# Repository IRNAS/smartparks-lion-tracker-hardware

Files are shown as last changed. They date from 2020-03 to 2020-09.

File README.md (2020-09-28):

# Smart Parks Lion Tracker Hardware

# Lion Tracker Hardware
 

<br>

PCB view:
<p align="center">
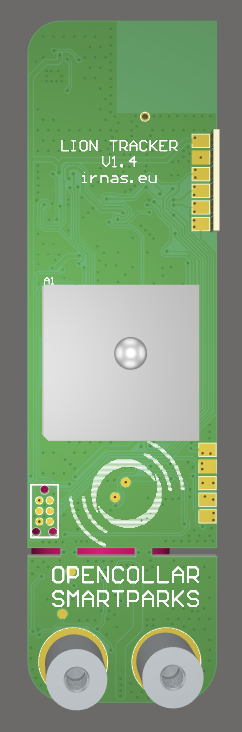
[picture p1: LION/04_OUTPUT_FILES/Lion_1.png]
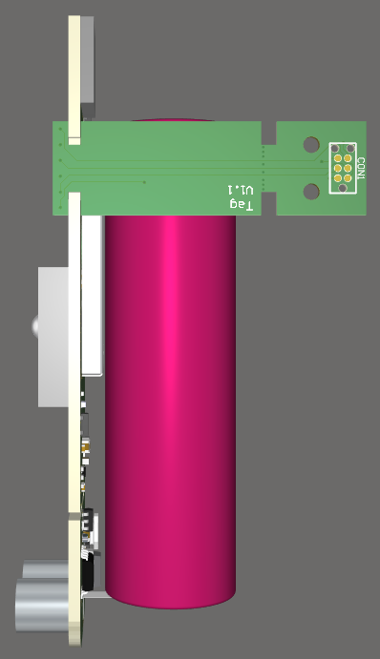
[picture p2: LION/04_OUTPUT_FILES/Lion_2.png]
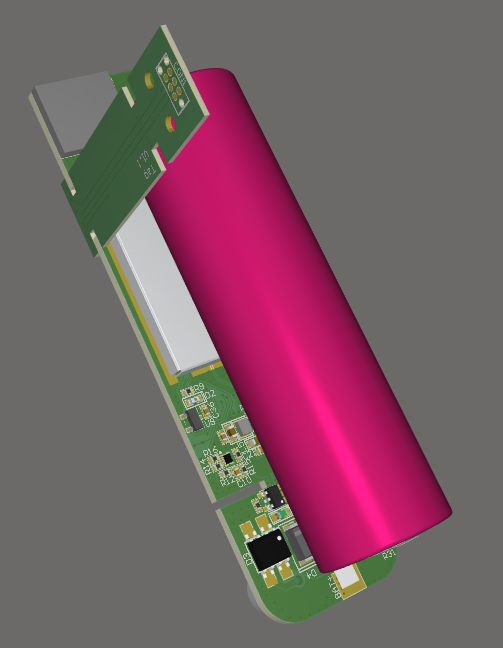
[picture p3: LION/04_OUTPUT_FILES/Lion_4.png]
							
</p>

Potted view:
<p align="center">
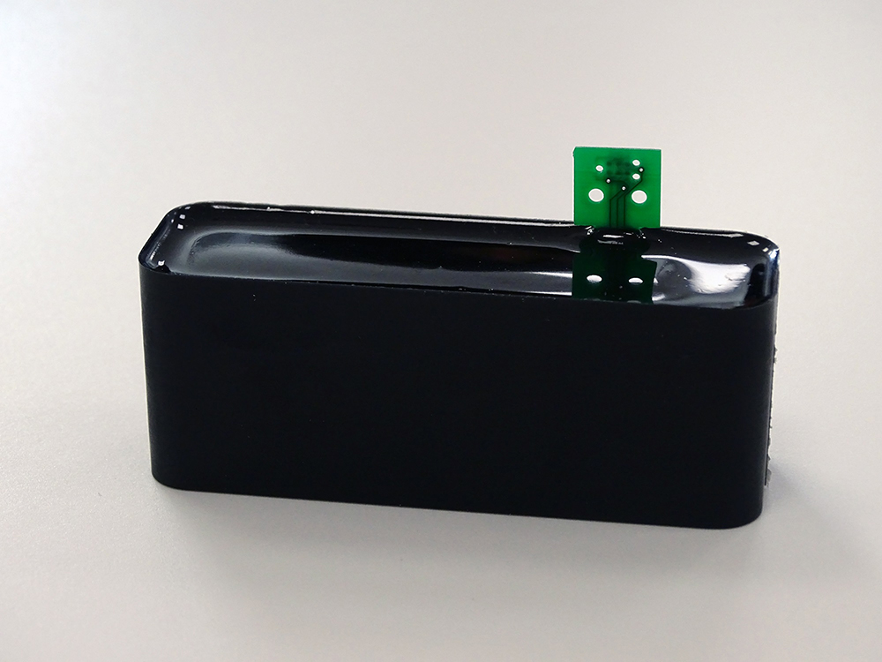
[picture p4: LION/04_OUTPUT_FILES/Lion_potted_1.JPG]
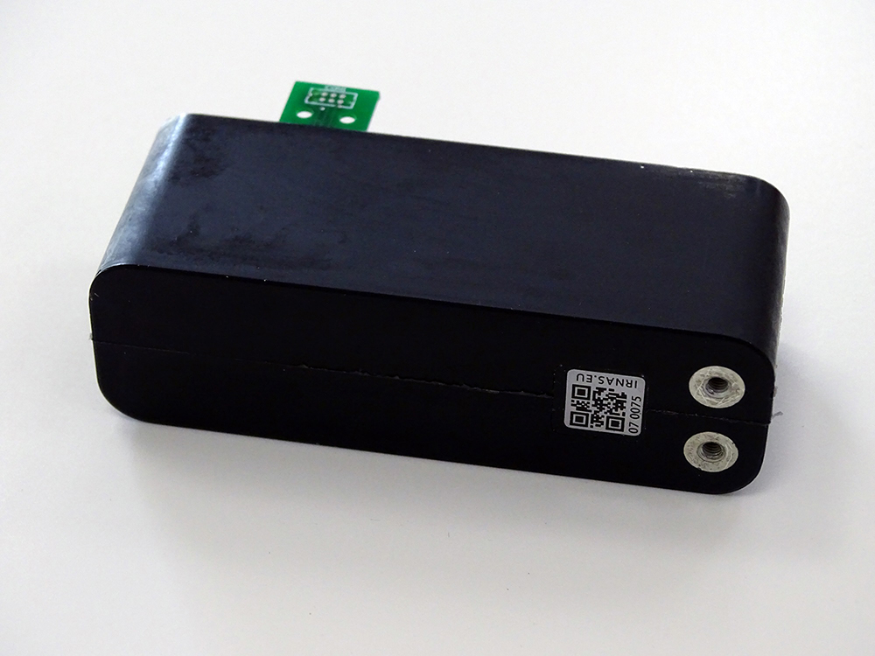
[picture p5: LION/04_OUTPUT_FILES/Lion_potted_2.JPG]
			
</p>

- PCB specifications:
	- 1.6mm PCB thinknes
	- 0.152mm (6mil) trace to trace and trace to polygon clearance
	- 1mm RF line thinknes

- Mehanical specifications:
	- Device dimensions 87x28x33mm
	- Device weight: ~125g
	- Device is put in polyurethane resin to protect it (https://electrolube.com/product/ur5528-chemically-resistant-polyurethane-resin/)
	- Inside of the device is EMC shield around MCU and RF components to protect them from resin
	- Resin thinknes arount the device is 2mm

- Future changes:
	- TBD
	
# Lence monitor add-on

- PCB specifications:
	- 1.6mm PCB thinknes
	- 0.152mm (6mil) trace to trace and trace to polygon clearance
	- Extra 3mm cut-out for protecting measuring circuit from high voltage discharge
	- Used as add-on for lion tracker
	
<p align="center">
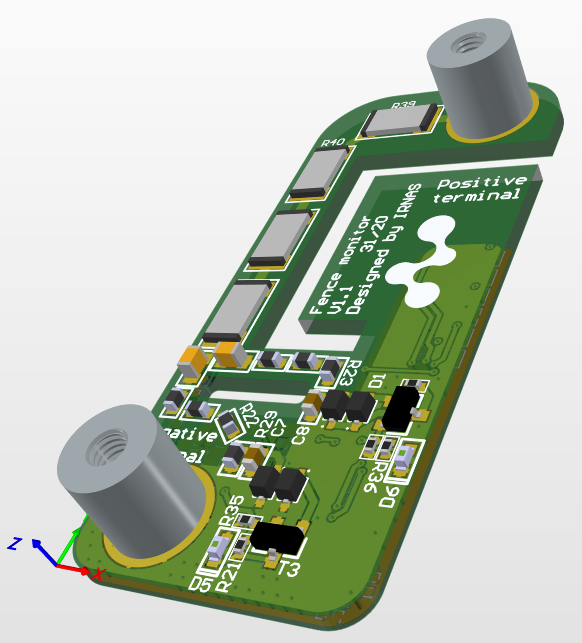
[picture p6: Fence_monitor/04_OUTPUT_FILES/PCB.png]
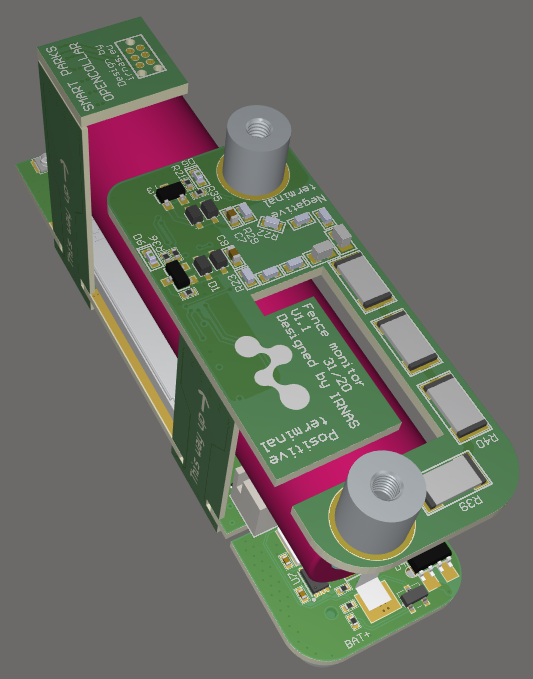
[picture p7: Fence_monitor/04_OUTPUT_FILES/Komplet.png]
			
</p>
	
Currently under development, for all information see the [schematic PDF file](https://github.com/IRNAS/smartparks-lion-tracker-hardware/blob/master/LION/06_RELEASE/V1.3/Lion_Tracker_V1.3_SCHEMATICS/Lion_Tracker_V1.3_SCHEMATICS.PDF).Produced board versions can be found in the [release section](https://github.com/IRNAS/smartparks-lion-tracker-hardware/releases) of the repository.

**Latest release: [v1.5](https://github.com/IRNAS/smartparks-lion-tracker-hardware)**

All comments and suggestions can be added to the [Issues](https://github.com/IRNAS/smartparks-lion-tracker-hardware/issues) section of the repo.

---

## Licensing

Lion tracker hardware with documentation is licensed under [CERN OHL v.1.2. license](https://www.ohwr.org/licenses/cern-ohl/license_versions/v1.2).

What this means is that you can use this hardware and documentation without paying a royalty and knowing that you'll be able to use your version forever. You are also free to make changes but if you share these changes then you have to do so on the same conditions that you enjoy.

IRNAS is name and mark of Institute IRNAS Rače. You may use these name and terms only to attribute the appropriate entity as required by the Open Licence referred to above. You may not use them in any other way and in particular you may not use them to imply endorsement or authorization of any hardware that you design, make or sell.

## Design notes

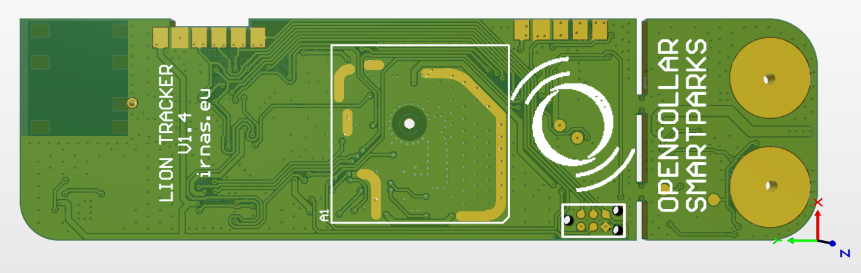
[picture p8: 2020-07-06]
LION/04_OUTPUT_FILES/Lion_5.png

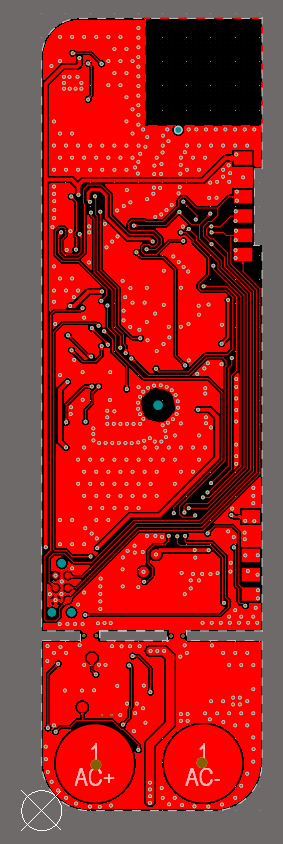
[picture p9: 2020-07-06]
LION/04_OUTPUT_FILES/Lion_8.png

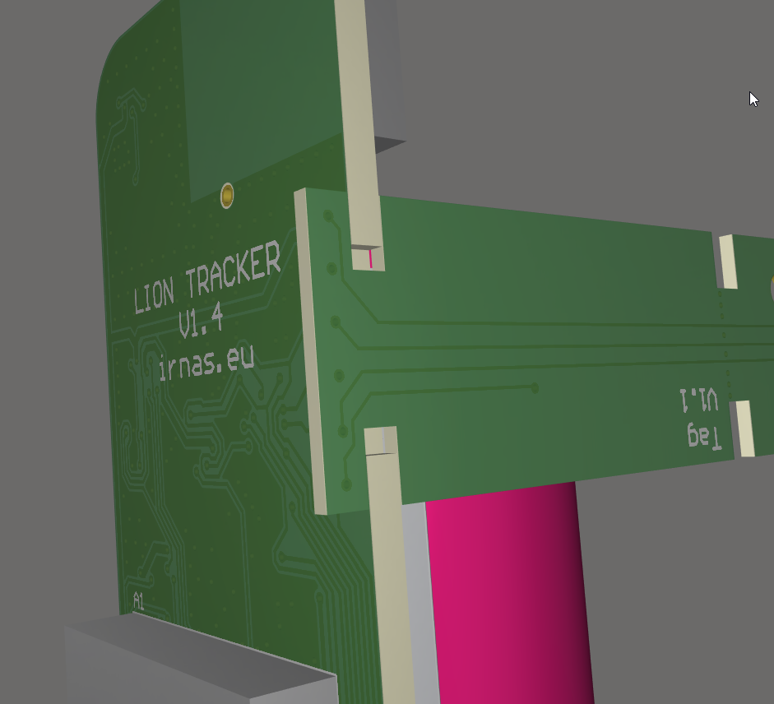
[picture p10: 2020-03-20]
LION/04_OUTPUT_FILES/Lion_3.png

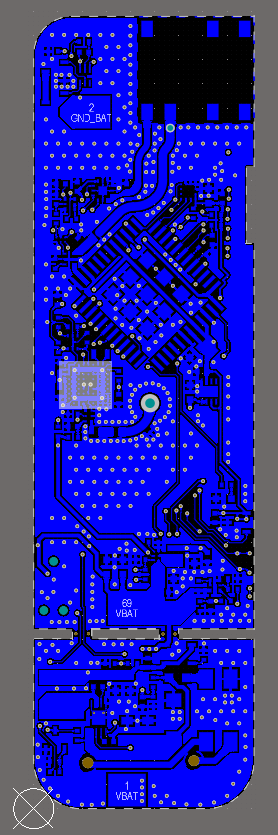
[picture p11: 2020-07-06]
LION/04_OUTPUT_FILES/Lion_7.png

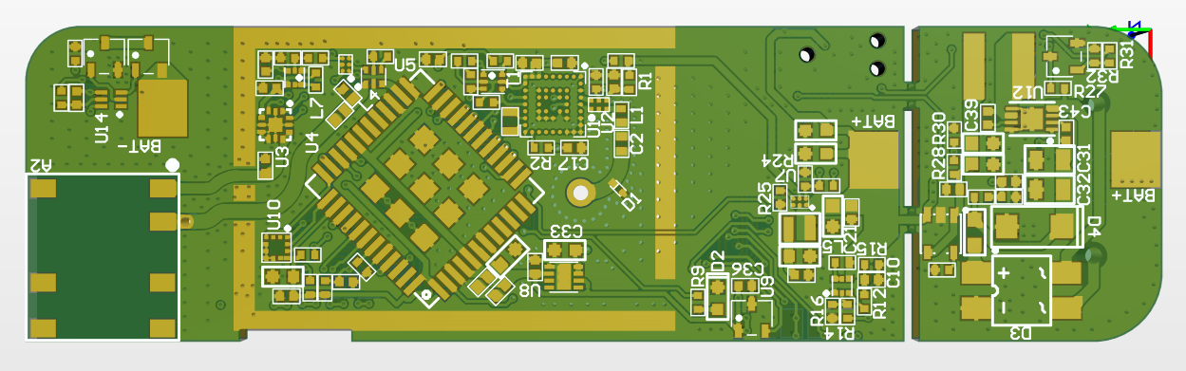
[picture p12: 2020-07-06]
LION/04_OUTPUT_FILES/Lion_6.png

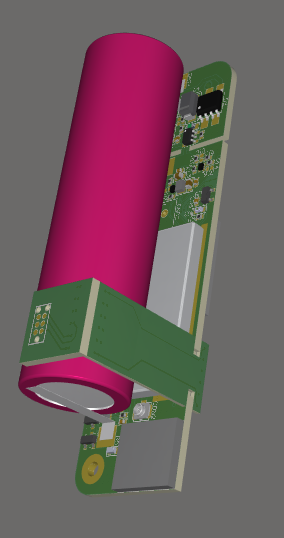
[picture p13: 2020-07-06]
LION/04_OUTPUT_FILES/Lion_10.png

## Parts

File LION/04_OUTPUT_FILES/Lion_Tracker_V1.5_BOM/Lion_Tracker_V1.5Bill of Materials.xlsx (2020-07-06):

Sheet: Part List Report
 | Component list |  |  | Lion_Tracker
 | Source Data From: | Lion tracker.PrjPCB
 | Project: | Lion tracker.PrjPCB
 | Variant: | BASIC |  |  | IRNAS
 | Report Date: | 12. 05. 2020 | 13:15 |  | www.irnas.eu
 | Print Date: | 2020-05-12 | 14:35:35
# | Manufacturer Part Number | Manufacturer | Description | Footprint | Designator | Quantity | Supplier 1 | Supplier Part Number 1
1 | 9HT11-32.768KEZC-T | TXC | Crystal, 32.768 kHz, SMD, 2mm x 1.2mm, 9 pF, 10 ppm, 9HT11 Series | 9HT11 | X1 | 1 | Farnell | 2819312
2
3 | MC0402X104J160CT | Multicomp | 0.1 F, 16 V, 5%, X5R, MC Series | CAP0402 | C4, C6, C8, C11, C14, C16, C21, C22, C39, C45 | 10 | Farnell | 2627419
4 | MC0402N3R9C500CT | KEMET | 3.9 pF, 50 V, 0402 [1005 Metric], ± 0.25pF, NP0 | CAP0402 | C7 | 1 | Farnell | 2627407
5 | MC0402X333K160CT | Multicomp | 33 pF, 16 V, 5%, C0G / NP0, MC Series | CAP0402 | C1 | 1 | Farnell | 1759384
6 | GRT155R71H471KE01D | Murata | 470 pF, 50 V, 0402 [1005 Metric], ± 10%, X7R, GRT Series | CAP0402 | C2 | 1 | Farnell | 2672128
7 | 0402ZD105MAT2A | Murata | CAP CER 1UF 10V 20% X5R 0402 | CAP0402 | C3, C13, C15, C36, C40, C43 | 6 | Farnell | 2332548
8 | GRM155R60J225ME15D | Murata | CAP CER 2.2UF 6.3V 20% X5R 0402 | CAP0402 | C34 | 1 | Farnell | 2362088
9 | 0402YC103KAT2A | Murata | CAP CER 10000PF 16V X7R 0402 | CAP0402 | C17 | 1 | Farnell | 1327662
10 | GRM188R61C475KAAJD | MURATA | 4.7UF, 16V, 0603 | CAP0603 | C33 | 1 | Farnell | 2611924
11 | GRM188R60G226MEA0D | Samsung | 22 µF, 4 V, 0603 [1608 Metric], ± 20%, X5R, GRM Series | CAP0603 | C23 | 1 | Farnell | 1907502
12 | CL10A106KP8NNNC | Samsung | Cap Ceramic 10uF 10V X5R 10% SMD 0603 85C Paper T/R | CAP0603 | C5, C12, C18, C19, C20, C41, C42 | 7 | Digi-Key | 3013386
13 | GRM21BR6YA106KE43L | TDK | 10UF, 35V, 0805 | CAP0805 | C31, C32 | 2 | Farnell | 2611943
14 | SMAJ33A-13-F | DIODES INC. | TVS Diode, SMAJ Series, Unidirectional, 33 V, 53.3 V, DO-214AC | DO-214AC (SMA) | D4 | 1 | Farnell | 3127459
15 | LMH2110TMX/NOPB | Texas Instruments | RF Detector IC GSM, EDGE, CDMA 50MHz ~ 8GHz -40dBm ~ 5dBm ±0,5dB | DSBGA-6 | U6 | 1 | Mouser | 926-LMH2110TMX/NOPB
16 | 0603L035YR | LITTELFUSE | LITTELFUSE - 0603L035YR - RESETTABLE FUSE, PTC, 40A, 6V, 0605 | FUSE0603 | F1 | 1 | Farnell | 2786561
17 | HHM22106C1 | TDK | Signal Conditioning DIRECTIONAL COUPLER 700-2700MHz | HHM22106C1 | U5 | 1 | Mouser | 810-HHM22106C1
18 | SRN2009T-2R2M | Bourns | Power Inductor (SMD), 2.2 µH, 900 mA, Semishielded, 900 mA, SRN2009T Series, 2mm x 1.6mm x 0.95mm | IND2.3X1.7 | L5 | 1 | Farnell | 2808272
19 | LQG15HS1N5S02D | Murata | 1.5 nH, LQG15HS_02 Series, 1 A, 0402 | IND0402 | L7 | 1 | Farnell | 2840113
20 | LQG15HS33NJ02D | Murata | High Frequency Inductor, 8.2 nH, LQG15HN Series, 300 mA, 0402 [1005 Metric], Multilayer, 0.33 ohm | IND0402 | L1 | 1 | Farnell | 1343079
21 | LIS2DW12TR | STMICROELECTRONICS | MEMS Accelerometer, Digital, X, Y, Z, ± 2g, ± 4g, ± 8g, ± 16g, 1.62 V, 3.6 V | LGA-12 | U10 | 1 | Farnell | 2849615
22 | CMWX1ZZABZ-091 | Murata | RF Module, FSK, OOK, LoRa, 4.8Kbps, 915MHz, -135.5dBm, 2.2V to 3.6V, I2C, SPI, UART, USB | Lora Module ES0 | U4 | 1 | Mouser | 81-CMWX1ZZABZ-091
23 | MB1S | ON SEMICONDUCTOR | Bridge Rectifier Diode, Single Phase, 100 V, 500 mA, SOIC, 1 V, 4 Pins | MB1S | D3 | 1 | Farnell | 1467483
24
25 | BQ29700DSET | TEXAS INSTRUMENTS | Li-Ion Battery, Li-Pol Voltage & Current Protector, Single Cell, 1.5 V to 8 V supply, | PWSON-6 | U14 | 1 | Farnell | 3123826
26 | PE64102B-Z | pSemi | RF IC Digitally Tunable Capacitor General Purpose 100MHz ~ 3GHz SPI Interface 12-QFN (2x2) | QFN-12 | U3 | 1 | Digi-Key | 1046-1066-1-ND
27 | MCWR04X2001FTL | Multicomp | 2 kohm, 62.5 mW, 1%, 50 V | RES0402 | R29 | 1 | Farnell | 2447147
28 | MCWR04X2201FTL | Multicomp | 2.2 kohm, 62.5 mW, 1%, 50 V | RES0402 | R36 | 1 | Farnell | 2447148
29 | MCWR04X1002FTL | Multicomp | 10 kohm, 50 V, 0402 [1005 Metric], 62.5 mW, 1%, MCWR Series, 10 kohm, 50 V, 0402, 62.5 mW, 1%, | RES0402 | R10, R11, R17, R18, R30, R34 | 6 | Farnell | 2447096
30 | CRCW040249R9FKED | Vishay | 49.9 ohm, CRCW e3 Series, 50 V, Thick Film, 63 mW | RES0402 | R19 | 1 | Farnell | 1469722
31 | MCMR04X5232FTL | Multicomp | 52.3 kohm, 50 V, 0402 [1005 Metric], 62.5 mW, 1%, MCWR Series | RES0402 | R28 | 1 | Farnell | 2073114
32 | MCMR04X1000FTL | Multicomp | 100 ohm, 50 V, 0402 [1005 Metric], 62.5 mW, 1% | RES0402 | R2, R14, R21, R23, R31 | 5 | Farnell | 2072515
33 | MCWR04X1003FTL | Multicomp | 100KOHM, 1%, 0.0625W | RES0402 | R4, R5, R6, R7, R8, R13, R20 | 7 | Farnell | 2447094
34 | MCWR04X3900FTL | Multicomp | 390 ohm, MCWR Series, 50 V, Thick Film, 62.5 mW | RES0402 | R15 | 1 | Farnell | 2447165
35 | MC0063W060311M | MULTICOMP | MCMR04X1004FTL RES, 1M, 1%, 0.0625W, 0402, THICK FILM | RES0402 | R3, R22, R27 | 3 | Farnell | 9330410
36 | MCMR04X3300FTL | Multicomp | MULTICOMP MCMR04X3300FTL Surface Mount Chip Resistor, Ceramic, MCMR Series, 330 ohm, 62.5 mW, 1%, 50 V, 0402 [1005 Metric], 330 ohm, 62.5 mW, 1%, 50 V, 0402 [1005 Metric] | RES0402 | R12, R35 | 2 | Farnell | 2692084
37 | MCMR04X1653FTL | Vishay | RES SMD 165K OHM 1% 1/16W 0402 | RES0402 | R33 | 1 | Farnell | 2072686
38 | MCMR04X000PTL | Multicomp | RESISTOR, 0402, 0R, ANTI SULFURATION | RES0402 | R1 | 1 | Farnell | 2072513
39 | WR04X7683FTL | Multicomp | RESISTOR, 0402, 768k, ANTI SULFURATION | RES0402 | R25 | 1 | Farnell | 2670555
40 | ZOE-M8G | U-Blox | ZOE-M8 RF Receiver BeiDou, Galileo, GLONASS, GNSS, GPS -160dBm | S-LGA51 | U1 | 1 | Digi-Key | 672-ZOE-M8G-0-10CT-ND
41 | ESD9R3.3ST5G | ON SEMICONDUCTOR | TVS Diode, ESD9R Series, Unidirectional, 3.3 V, 7.8 V | SOD-923 | D1 | 1 | Farnell | 2101835
42 | DRV5032FBDBZR | Texas Instruments | Board Mount Hall Effect/Magnetic Sensors LP HALL 32FBDBZR | SOT23-3AL | U9 | 1 | Mouser | 595-DRV5032FBDBZR
43 | DMG2302UK-7 | DIODES INC. | MOSFET Transistor, N Channel, 2.8 A, 20 V, 0.061 ohm, 4.5 V, 600 mV | SOT23-3AL | T4 | 1 | Farnell | 3127526
44 | SI2374DS-T1-GE3 | VISHAY | MOSFET Transistor, N Channel, 5.9 A, 20 V, 0.025 ohm, 4.5 V, 1 V | SOT23-3AL | T5, T6 | 2 | Farnell | 2646371
45 | MCP73812T-420I/OT | MICROCHIP | Battery Charger for 1 Cell of Li-Ion, Li-Pol battery, 6V input, 4.2V / 500mA charge | SOT23-5 | U13 | 1 | Farnell | 1627187
46 | NTZD3154NT1G | ON SEMICONDUCTOR | Dual MOSFET, Dual N Channel, 540 mA, 20 V, 0.4 ohm, 4.5 V, 1 V | SOT-563 | T1 | 1 | Farnell | 2533209
47 | BAS70-05,215 | NEXPERIA | Small Signal Schottky Diode, Dual Common Cathode, 70 V, 70 mA, 410 mV, 100 mA, 150 °C | SOT 23 | D5 | 1 | Farnell | 1081186
48 | SR42I010-L | Antenova | Antenna SMD -4dBi Gain 870MHz/928MHz Automotive 7-Pin SMD T/R | SR42I010-L | A2 | 1 | Mouser | 237-SR42I010-L
49 | SRN5020TA-220M | Bourns | Power Inductor (SMD), 22 µH, 1.1 A, Semishielded, 1.1 A, SRN5020TA Series, 5mm x 5mm x 1.8mm | SRN5020TA | L6 | 1 | Mouser | 652-SRN5020TA-220M
50 | MCP16311T-E/MNY | MICROCHIP | DC-DC Synchronous Buck Regulator, Adjustable, 4.4V to 30V In, 2V to 24V/1A Out, 500kHz | TDFN-8 | U12 | 1 | Farnell | 2857600
51
52 | MAX2659ELT+T | MAXIM INTEGRATED PRODUCTS | RF Amplifier, GPS / GNSS, 20.5 dB Gain / 0.8 dB Noise, 1575.42 MHz, 1.6 V to 3.3 V Supply | uDFN-6 | U2 | 1 | Farnell | 2800966
53 | MCP1810T-25I/J8A | MICROCHIP | LDO Voltage Regulator, Fixed, 2.5 V to 5.5 V in, 2.5 V/150 mA out, 380 mV drop | VDFN_2x2 | U8 | 1 | Farnell | 2678432
54 | VT6M1T2CR | ROHM | Dual MOSFET, N and P Channel, 100 mA, 20 V, 2.5 ohm, 4.5 V, 1 V | VMT6 | T2, T3 | 2 | Farnell | 2706721
55 | MAX38640AENT+T | Maxim Integrated | Switching Voltage Regulators Tiny 300nA nanoPower Buck converters in uDFN and WLP pacakges | WLP-6 | U7 | 1 | Mouser | 700-MAX38640AENT+

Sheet: Project Information
Project Full Path | D:\Synology Drive\IRNAS-Projects\SmartParks\SmartParks - Lion tracker\Electronics\LION\Lion tracker.PrjPCB
Project Filename | Lion tracker.PrjPCB
Variant Name | BASIC
Data-Source Filename | Lion tracker.PrjPCB
Data-Source Full Path | D:\Synology Drive\IRNAS-Projects\SmartParks\SmartParks - Lion tracker\Electronics\LION\Lion tracker.PrjPCB
Title | Bill of Materials for Variant [BASIC] of Project [Lion tracker.PrjPCB] (PCB Document : LION_TRACKER.PcbDoc)
Total Quantity | 99
Report Time | 13:15
Report Date | 12. 05. 2020
Report Date & Tine | 12. 05. 2020 13:15
Output Name | Bill of Materials
Output Type | BOM_PartType
Output Generator Name | BOM
Output Generator Description | Bill of Materials

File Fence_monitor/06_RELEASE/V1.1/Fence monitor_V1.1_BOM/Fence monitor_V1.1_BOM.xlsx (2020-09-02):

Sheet: Part List Report
 | Component list |  |  | Fence monitor
 | Source Data From: | Fence monitor.PrjPCB |  |  | Contact:
 | Project: | Fence monitor.PrjPCB
 | Variant: | Single_CH |  |  |  |  |  |  | IRNAS
 | Report Date: | 26. 08. 2020 | 09:06 |  |  |  |  |  | www.irnas.eu
 | Print Date: | 2020-08-26 | 9:06:49
# | Manufacturer Part Number | Manufacturer | Description | Footprint | Designator | Quantity | Supplier 1 | Supplier Part Number 1 | Supplier Order Qty 1 | Supplier Stock 1 | Supplier Unit Price 1 | Supplier Subtotal 1 | Supplier Currency 1
1 | GCM155R71H102KA37D | Murata | CAP CER 1000PF 50V X7R 0402 | CAP0402 | C14 | 1 | Farnell | 2470415
2 | GRM155R71C103KA01D | Murata | CAP CER 10000PF 16V X7R 0402 | CAP0402 | C15 | 1 | Farnell | 1828864
3 | MC0402X104J160CT | Multicomp | MULTICOMP MC0402X104J160CT SMD Multilayer Ceramic Capacitor, 0402 [1005 Metric], 0.1 F, 16 V, 5%, X5R, MC Series New | CAP0402 | C11, C16 | 2 | Farnell | 2627419
4 | C0402C189B5GACTU | KEMET | Multilayer Ceramic Capacitors MLCC - SMD/SMT 50volts 1.8pF C0G | CAP0402 | C9, C10 | 2 | Farnell | 2533789
5 |  |  |  | LOGO_1-10MM | LOGO1 | 1
6 | MCMR04X1000FTL | Multicomp | 100 ohm, 50 V, 0402 [1005 Metric], 62.5 mW, 1% | RES0402 | R6 | 1 | Farnell | 2072515
7 | MCWR04X1003FTL | Multicomp | 100KOHM, 1%, 0.0625W | RES0402 | R4 | 1 | Farnell | 2447094
8 | MC0063W060311M | MULTICOMP | MCMR04X1004FTL RES, 1M, 1%, 0.0625W, 0402, THICK FILM | RES0402 | R7 | 1 | Farnell | 9330410
9 | MCWR04X2001FTL | Multicomp | MULTICOMP MCWR04X2001FTL Surface Mount Chip Resistor, Thick Film, MCWR Series, 2 kohm, 62.5 mW, 1%, 50 V | RES0402 | R34 | 1 | Farnell | 2072887
10 | MCMR06X4702FTL | MULTICOMP | MULTICOMP - MCMR06X4702FTL - RES, CERAMIC, 47K, 1%, 0.1W, 0603 | RES0402 | R26, R28, R33 | 3 | Farnell | 1469719
11 | RCA060310R0FKEA | VISHAY | SMD Chip Resistor, 0402 [1005 Metric], 10 ohm, CRCW e3 Series, 50 V, Thick Film, 63 mW | RES0402 | R27 | 1 | Farnell | 1652742
12 | ERJ-3EKF2202V | Panasonic | SMD Chip Resistor, 0402 [1005 Metric], 22 kohm, MCWR Series, 50 V | RES0402 | R32 | 1 | Farnell | 2447137
13 | MCMR06X103 JTL | MULTICOMP | MULTICOMP - MCMR06X103 JTL - RES, CERAMIC, 10K, 5%, 0.1W, 0603 | RES0603 | R14, R20, R25 | 3 | Farnell | 2138424
14 | MCWR06X1503FTL | MULTICOMP | SMD Chip Resistor, 0603 [1608 Metric], 150 ohm, MCWR Series, 50 V, Thick Film, 100 mW | RES0603 | R30 | 1 | Farnell | 2447255
15 | MC0063W060311M | MULTICOMP | SMD Chip Resistor, 2512 [6432 Metric], 1 Mohm, CRCW e3 Series, 500 V | RES2512 | R9, R10, R39, R40 | 4 | Farnell | 2395991
16 | 1N4148W-7-F. | DIODES INC. | TVS Diode, µClamp Series, Unidirectional, 3.3 V, 9.5 V | SOD-323 | D7 | 1 | Farnell | 1456422
17 | TLV9052IDR | Texas Instruments | General Purpose Amplifier 2 Circuit Rail-to-Rail 8-SOIC | SOIC-8 REFLOW | U2 | 1 | Digi-Key | 296-53049-1-ND
18 | BC847B,215 | ON SEMICONDUCTOR | MOSFET Transistor, N Channel, 310 mA, 60 V, 0.86 ohm, 10 V, 1 V | SOT 23 | T4 | 1 | Farnell | 2317616
19 | VT6M1T2CR |  | Dual MOSFET, N and P Channel, 100 mA, 20 V, 2.5 ohm, 4.5 V, 1 V | VMT6 | T1 | 1 | Farnell | 2706721
20 |  |  | WP-SMBU SMD Internal blind-hole thread w. Pins | WP-SMBU | TAB1, TAB2 | 2 | Farnell | 2405986
 |  |  |  |  |  | 30 |  |  | 0 |  |  | 0
Approved |  |  |  | Notes
 |  |  |  | pcs: |  | 20 |  | Total |  | 0 |  | <none>
 |  |  |  |  |  |  |  | Price for 1pcs |  | 0.00 |  | <none>

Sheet: Project Information
Project Full Path | D:\Synology Drive\IRNAS-Projects\SmartParks\Smartparks - Fence monitor\Electronics\Fence monitor.PrjPCB
Project Filename | Fence monitor.PrjPCB
Variant Name | Single_CH
Data-Source Filename | Fence monitor.PrjPCB
Data-Source Full Path | D:\Synology Drive\IRNAS-Projects\SmartParks\Smartparks - Fence monitor\Electronics\Fence monitor.PrjPCB
Title | BOM for Variant [Single_CH] of Project [Fence monitor.PrjPCB] (No PCB Document Selected)
Total Quantity | 30
Report Time | 09:06
Report Date | 26. 08. 2020
Report Date & Tine | 26. 08. 2020 09:06
Output Name | BOM
Output Type | BOM_PartType
Output Generator Name | BOM
Output Generator Description | Bill of Materials

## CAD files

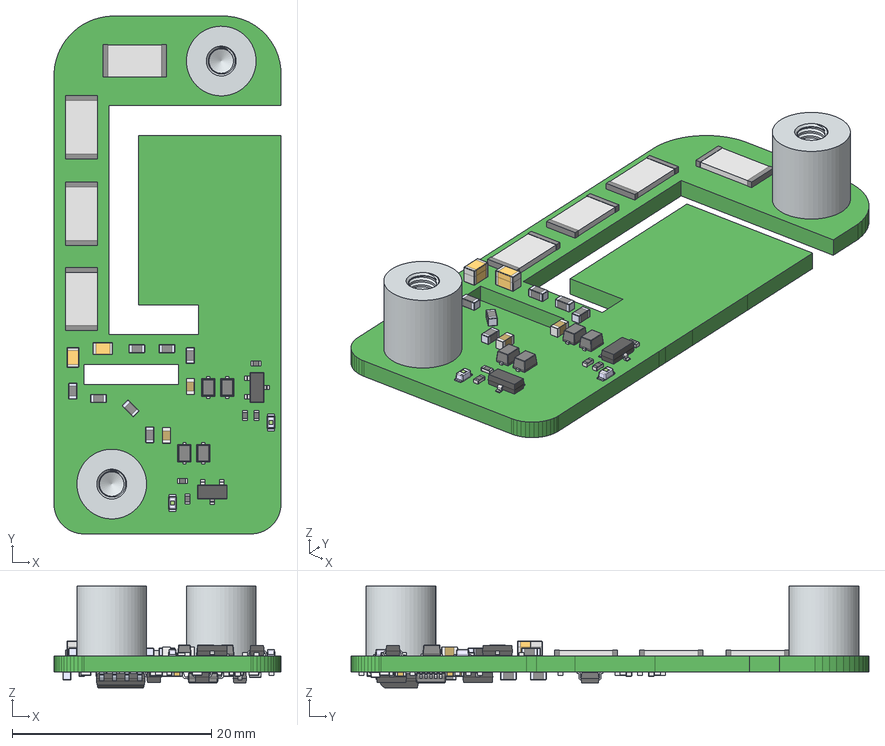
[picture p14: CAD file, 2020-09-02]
Fence_monitor/06_RELEASE/V1.1/Fence monitor_V1.1_3D/Fence monitor_V1.1_3D STEP.step
22.8 x 52.0 x 10.2 mm
SOD323
C_SMD_0603 x 2
R0603 x 11
Mid_Body x 29
Open_CASCADE_STEP_translator_6.8_3.2.1 x 58
Mark x 29
Open_CASCADE_STEP_translator_6.8_4.1.1 x 12
Open_CASCADE_STEP_translator_6.8_4.1.2 x 12
Open_CASCADE_STEP_translator_6.8_4.2.1 x 12
RESISTOR_2512 x 4
LED_SMD_0603 x 2
Extruded x 2
SW3DPS-SO-8_(PIC12FXXX)-DEFAULT
DGS0010A_ASM_LEAD-SO#LEAD-SO;LEAD-SO
DGS0010A_ASM_LEAD-SO#LEAD-SO;LEAD-SO_2
DGS0010A_ASM_LEAD-SO#LEAD-SO;LEAD-SO_3
DGS0010A_ASM_LEAD-SO#LEAD-SO;LEAD-SO_4
DGS0010A_ASM_LEAD-SO#LEAD-SO;LEAD-SO_5
DGS0010A_ASM_LEAD-SO#LEAD-SO;LEAD-SO_6
DGS0010A_ASM_LEAD-SO#LEAD-SO;LEAD-SO_7
DGS0010A_ASM_LEAD-SO#LEAD-SO;LEAD-SO_8
DGS0010A_ASM_LEAD-SO#LEAD-SO;LEAD-SO_9
DGS0010A_ASM_LEAD-SO#LEAD-SO;LEAD-SO_10
DGS0010A_ASM_BODY-SO#BODY-SO;BODY-SO
7466103_(rev1) x 2
SOT-23 x 4
VMT6_RGB16777215
Open_CASCADE_STEP_translator_6.8_11.1.1 x 4
lead x 8
CAPC2012X95N_EIA_0805 x 4

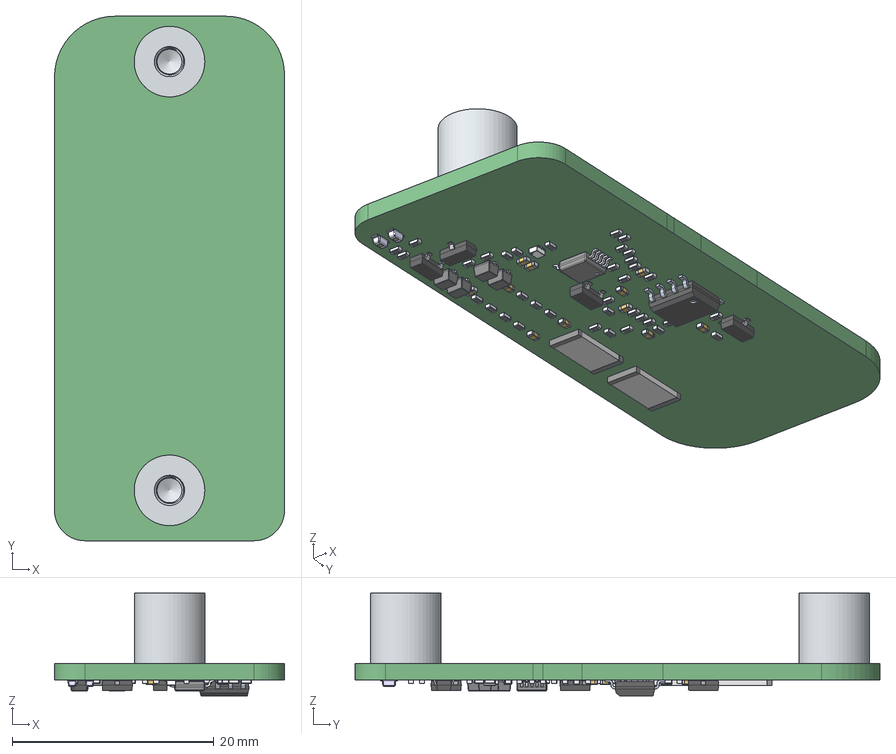
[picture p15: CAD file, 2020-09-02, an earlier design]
Fence_monitor/06_RELEASE/V1/Fence monitor_V1_3D/Fence monitor_V1_3D STEP.step
22.8 x 52.0 x 10.2 mm
Mid_Body x 36
Open_CASCADE_STEP_translator_6.8_3.2.1 x 72
Mark x 36
LED_SMD_0603 x 2
Extruded x 2
SW3DPS-SO-8_(PIC12FXXX)-DEFAULT
DGS0010A_ASM_LEAD-SO#LEAD-SO;LEAD-SO
DGS0010A_ASM_LEAD-SO#LEAD-SO;LEAD-SO_2
DGS0010A_ASM_LEAD-SO#LEAD-SO;LEAD-SO_3
DGS0010A_ASM_LEAD-SO#LEAD-SO;LEAD-SO_4
DGS0010A_ASM_LEAD-SO#LEAD-SO;LEAD-SO_5
DGS0010A_ASM_LEAD-SO#LEAD-SO;LEAD-SO_6
DGS0010A_ASM_LEAD-SO#LEAD-SO;LEAD-SO_7
DGS0010A_ASM_LEAD-SO#LEAD-SO;LEAD-SO_8
DGS0010A_ASM_LEAD-SO#LEAD-SO;LEAD-SO_9
DGS0010A_ASM_LEAD-SO#LEAD-SO;LEAD-SO_10
DGS0010A_ASM_BODY-SO#BODY-SO;BODY-SO
7466103_(rev1) x 2
SOT-23 x 4
VMT6_RGB16777215
RESISTOR_2512 x 2
Open_CASCADE_STEP_translator_6.8_11.1.1 x 4
lead x 8
Open_CASCADE_STEP_translator_6.8_4.1.1 x 11
Open_CASCADE_STEP_translator_6.8_4.1.2 x 11
Open_CASCADE_STEP_translator_6.8_4.2.1 x 11

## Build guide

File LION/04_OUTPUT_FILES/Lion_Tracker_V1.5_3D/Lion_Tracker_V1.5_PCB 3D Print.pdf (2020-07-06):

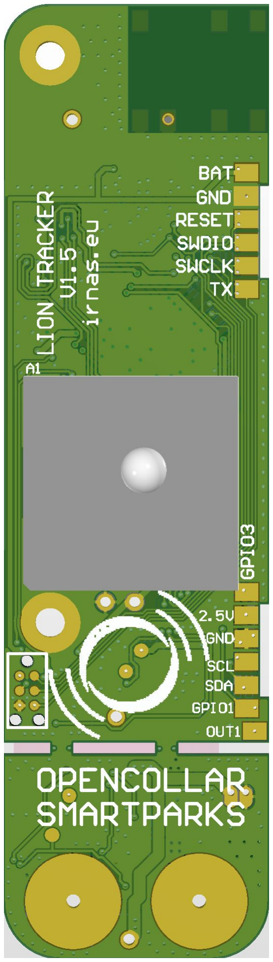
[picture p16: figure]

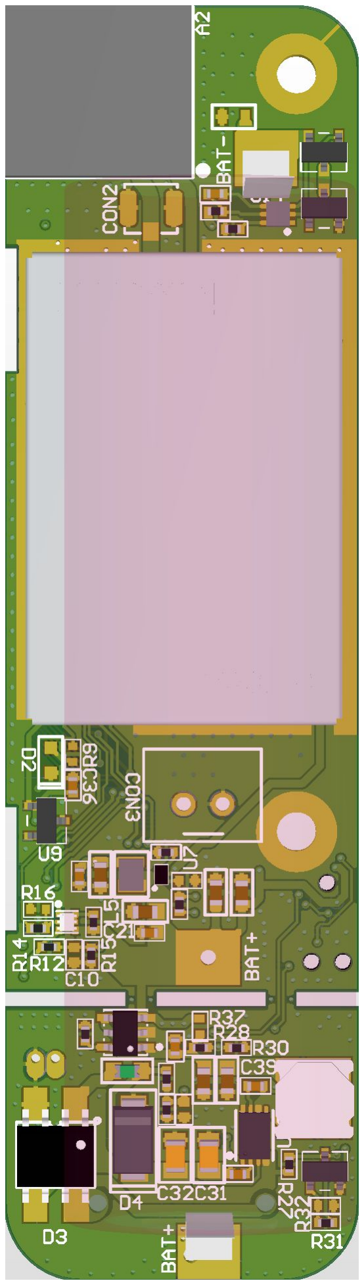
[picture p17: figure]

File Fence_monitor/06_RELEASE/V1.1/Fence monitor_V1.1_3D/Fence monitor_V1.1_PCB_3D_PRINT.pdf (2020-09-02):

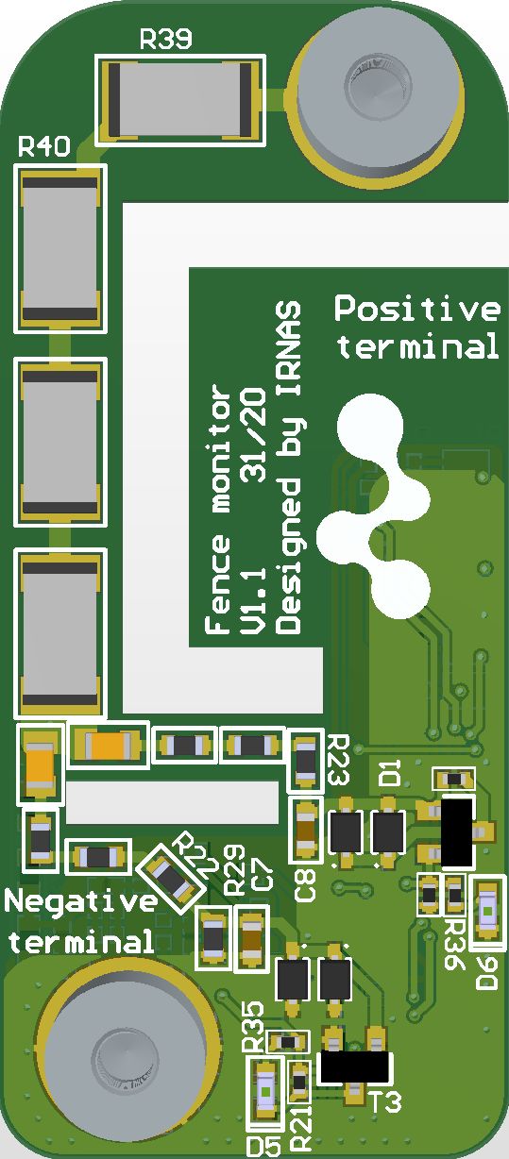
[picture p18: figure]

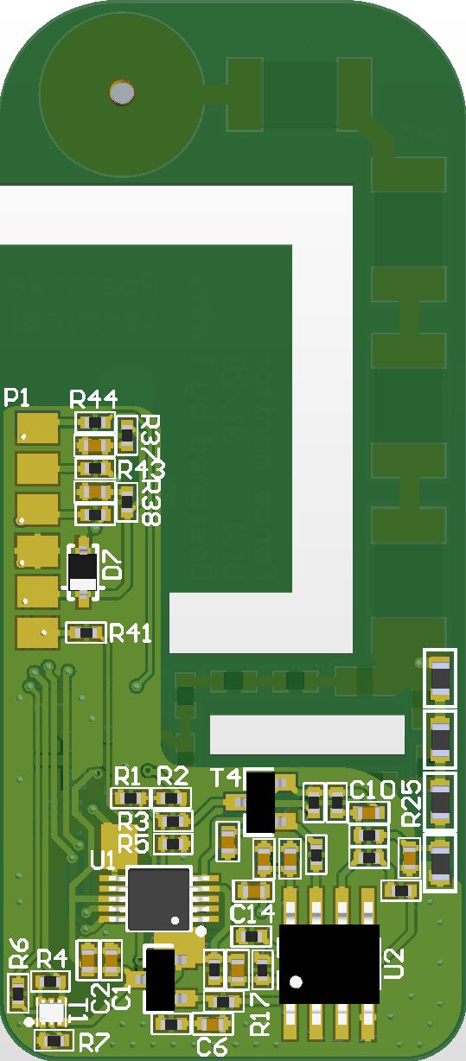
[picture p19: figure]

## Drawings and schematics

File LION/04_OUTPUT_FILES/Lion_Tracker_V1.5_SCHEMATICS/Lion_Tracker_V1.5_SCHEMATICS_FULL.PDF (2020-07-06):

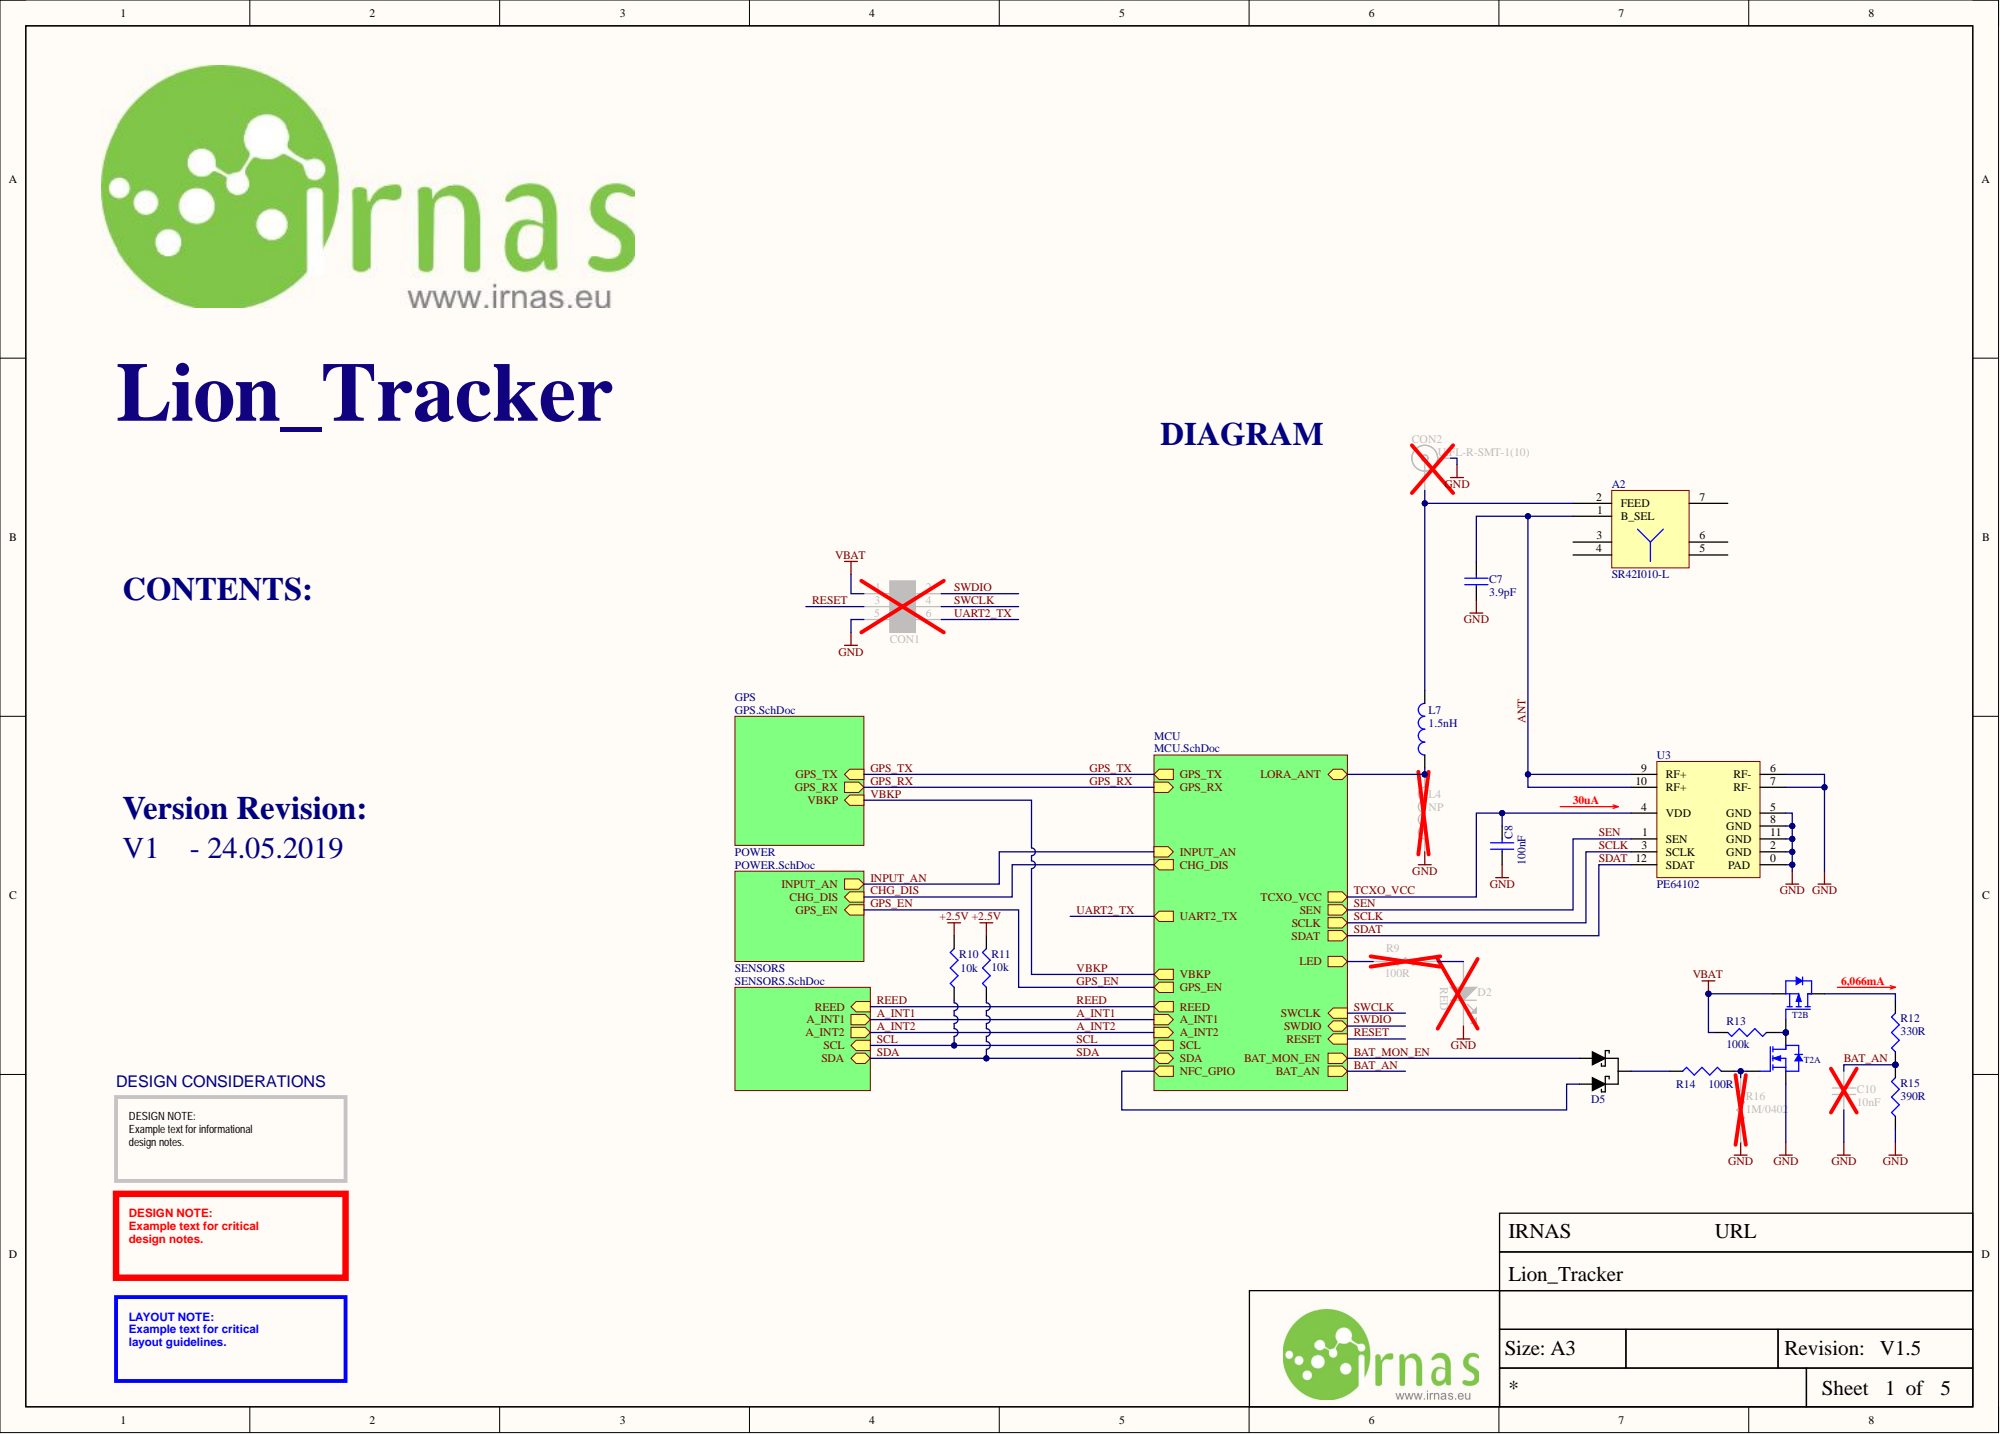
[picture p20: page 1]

SEN SCLK SDAT | 3 | | 2

SDAT 12 | 0

INPUT_A N | | | GND
CHG_DI S

UA RT2_TX | | TCXO_VCC SEN SCLK SDAT

DESIGN NOTE:
Example text for informational
design notes.

Example text for critical

LAYOUT NOTE:
layout guidelines.

Size: A3 | | Revision: V1.5

Sheet of

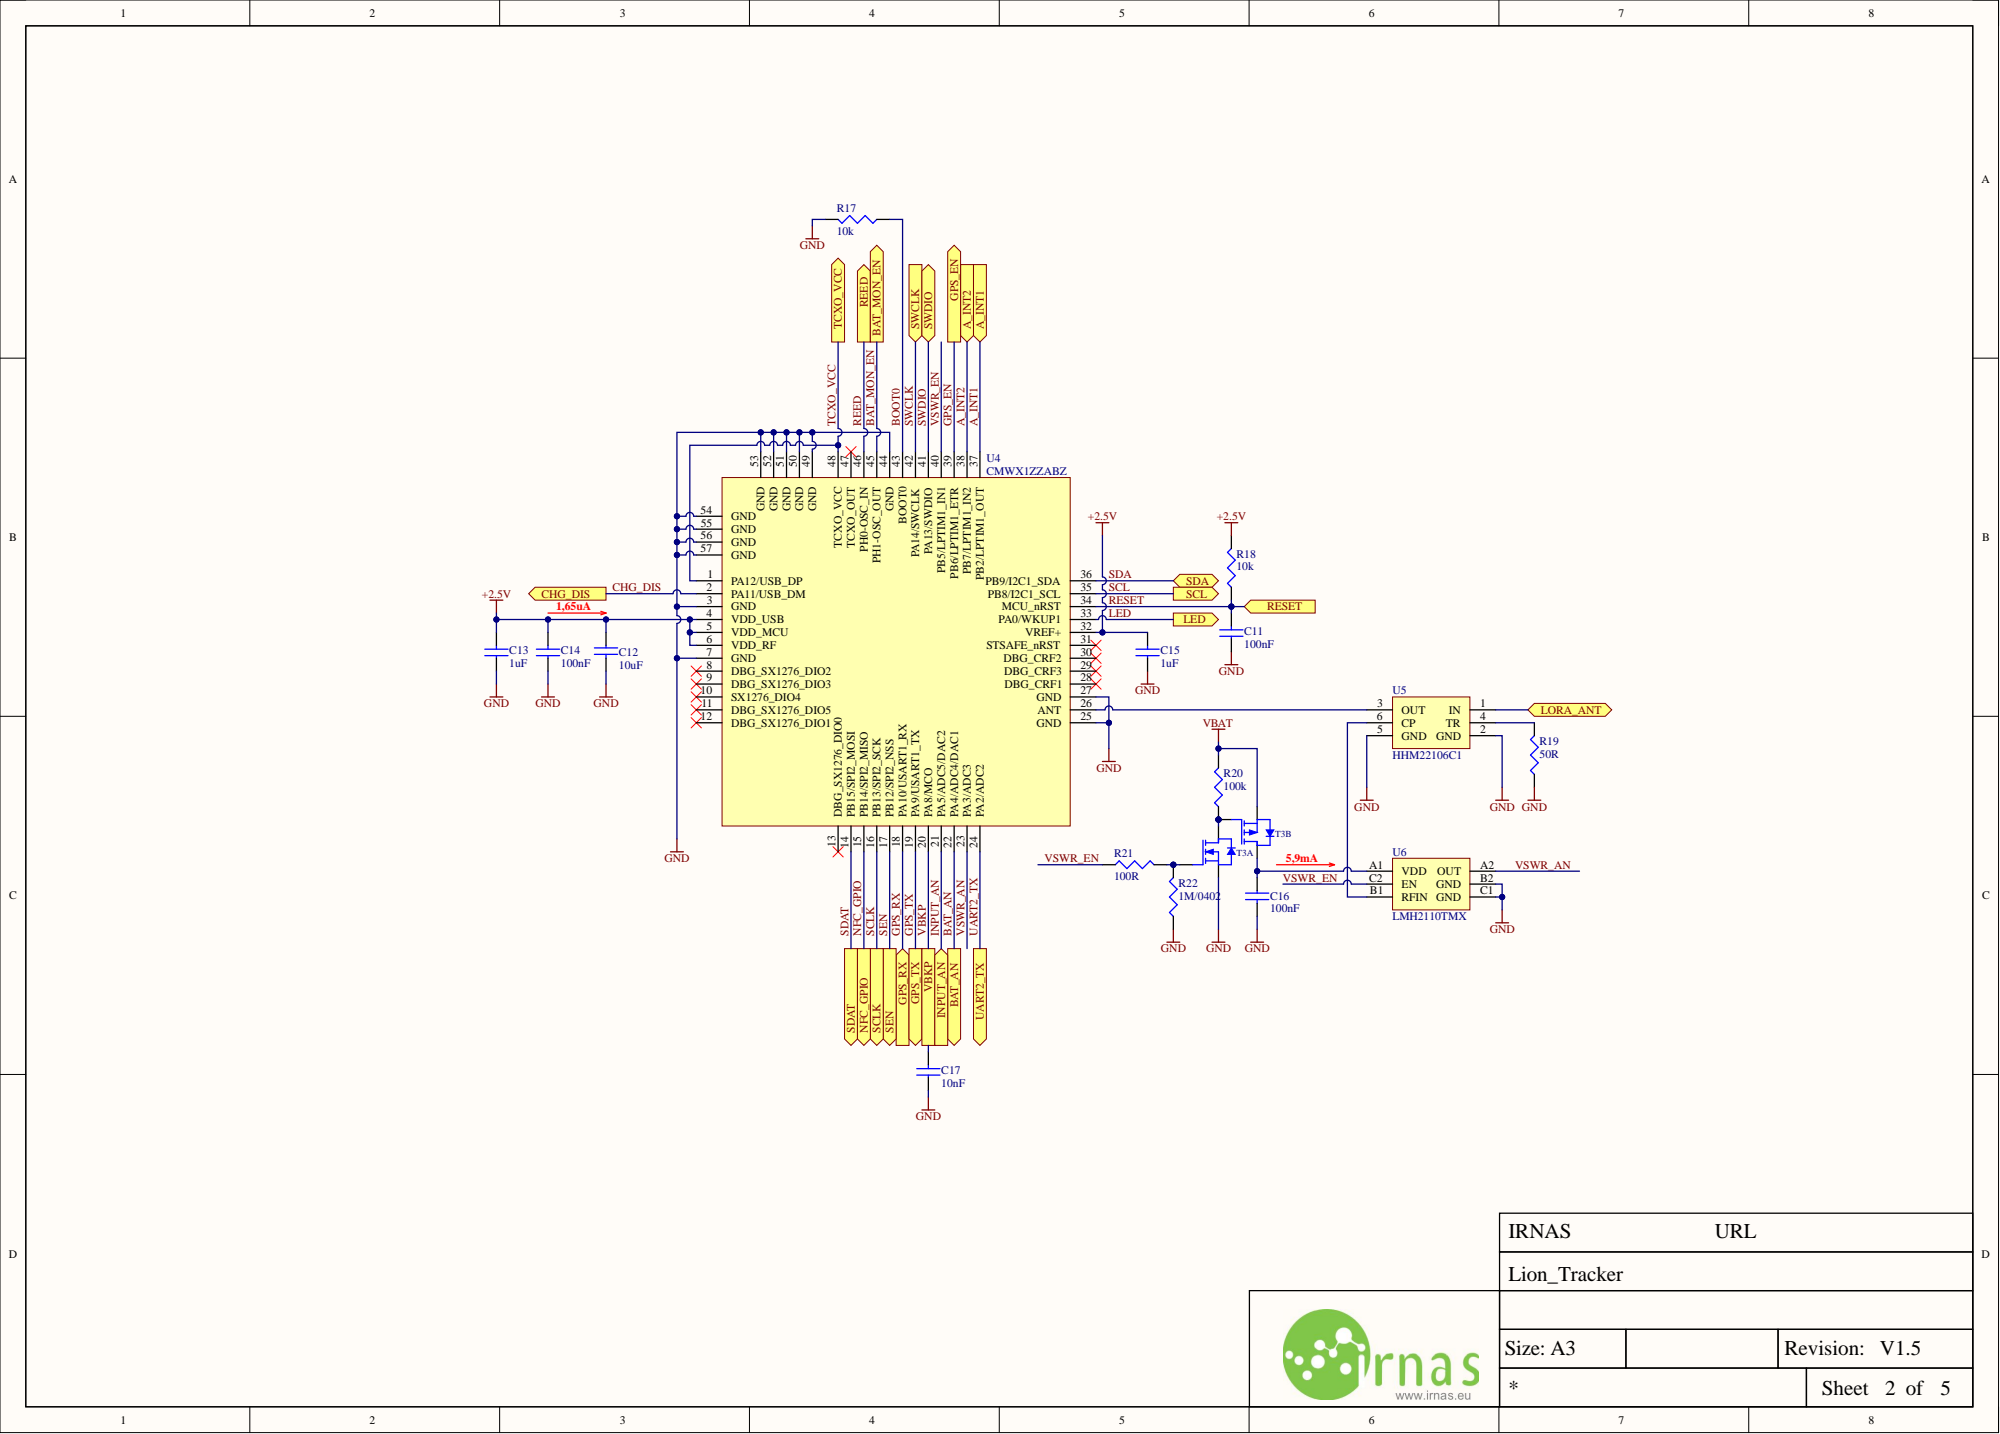
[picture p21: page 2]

GND 50 GND 51 GND 52 GND 53

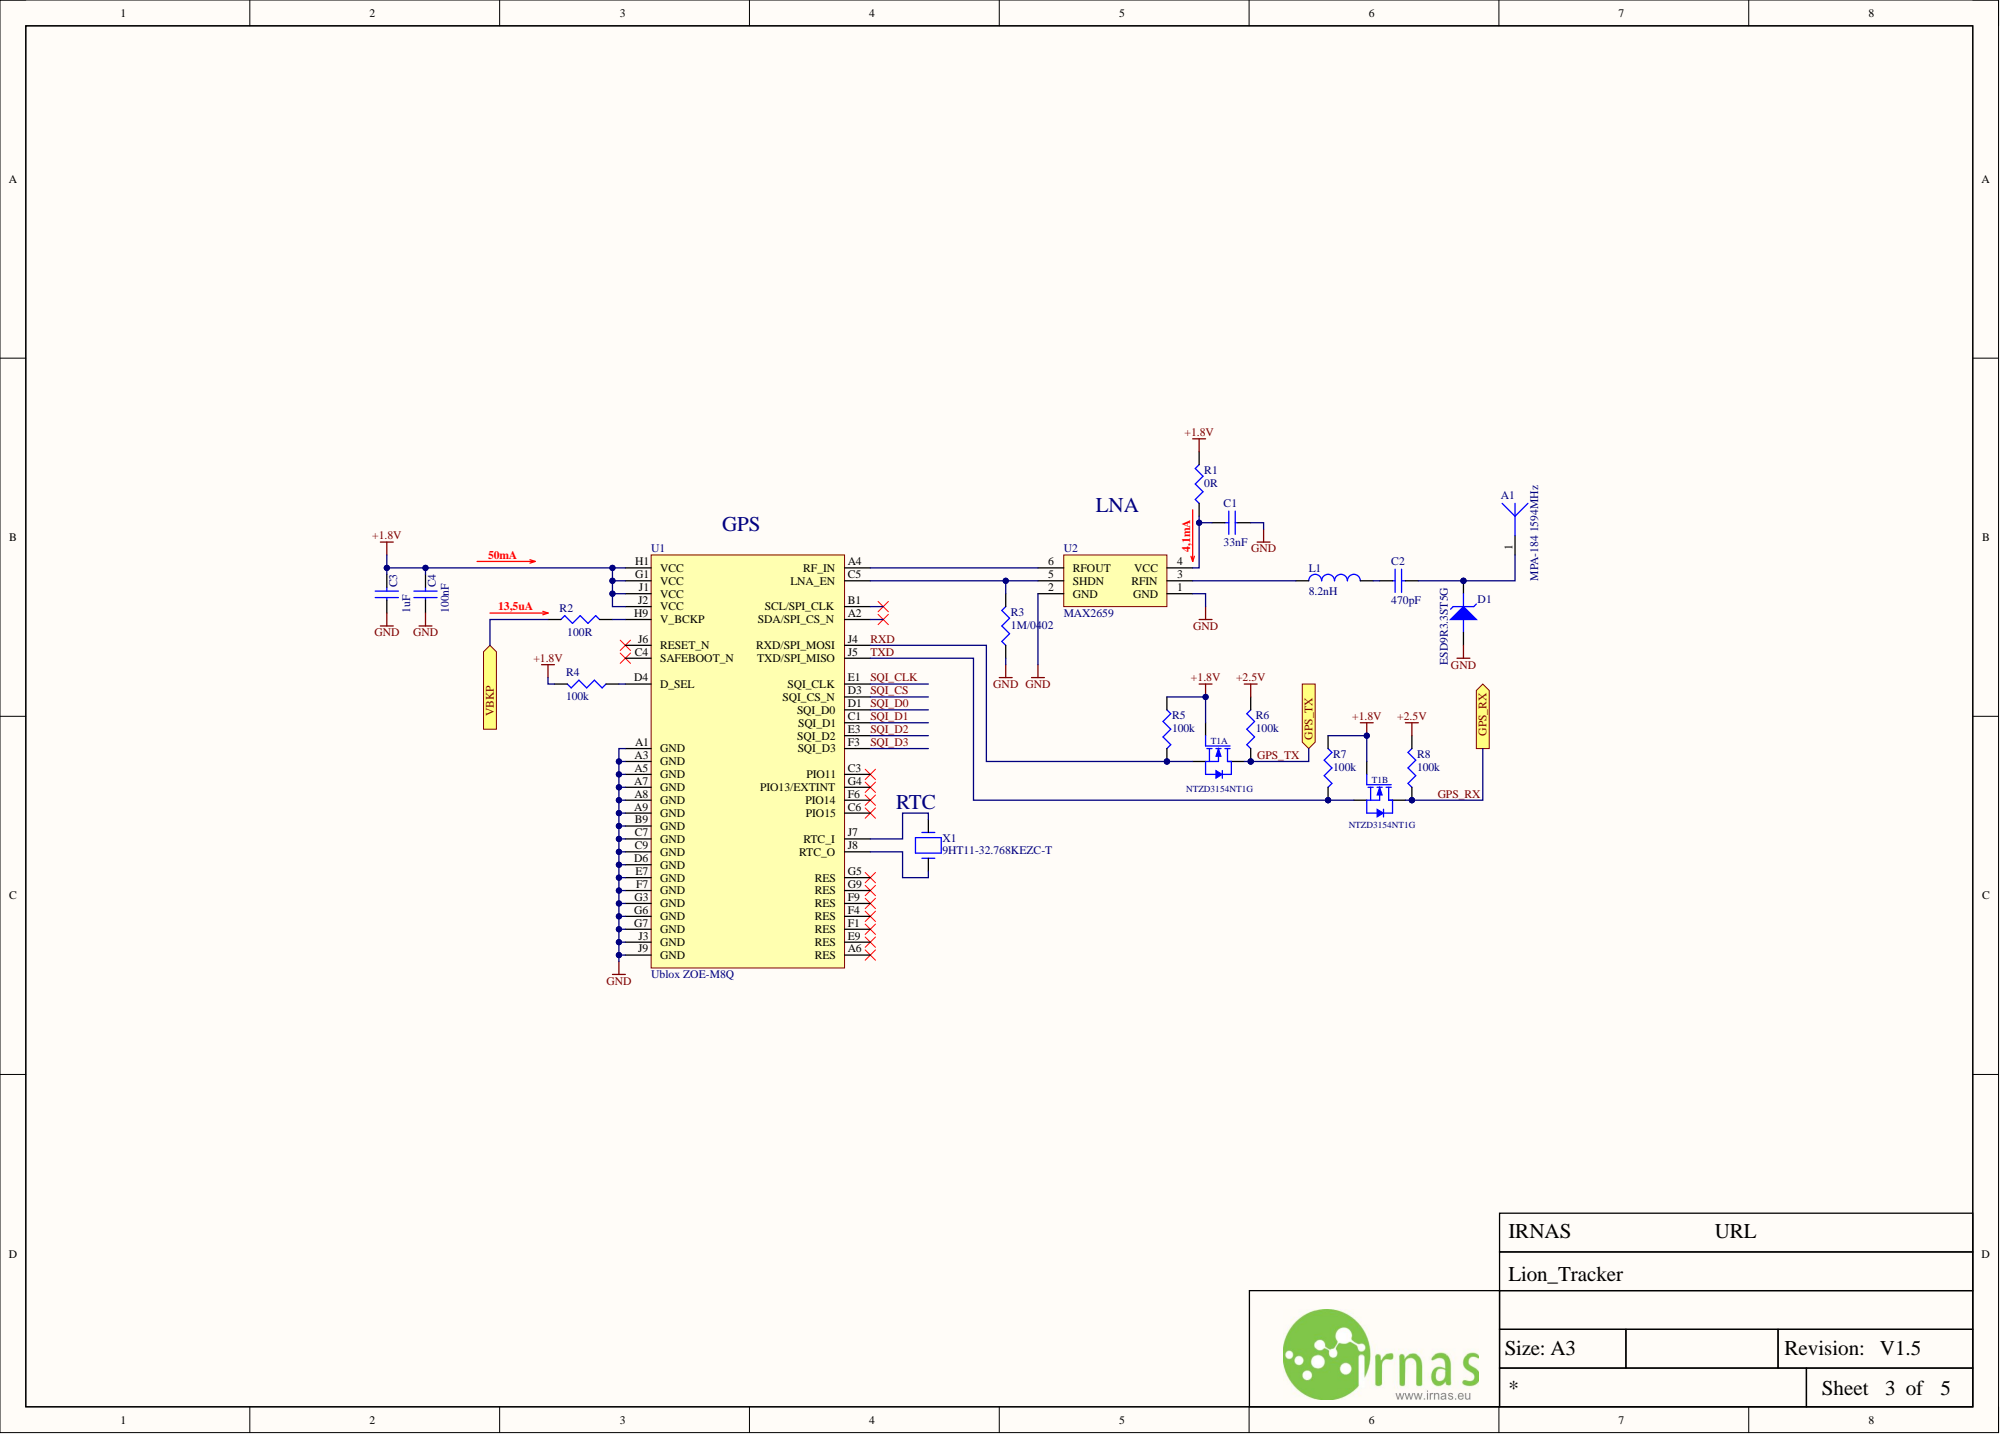
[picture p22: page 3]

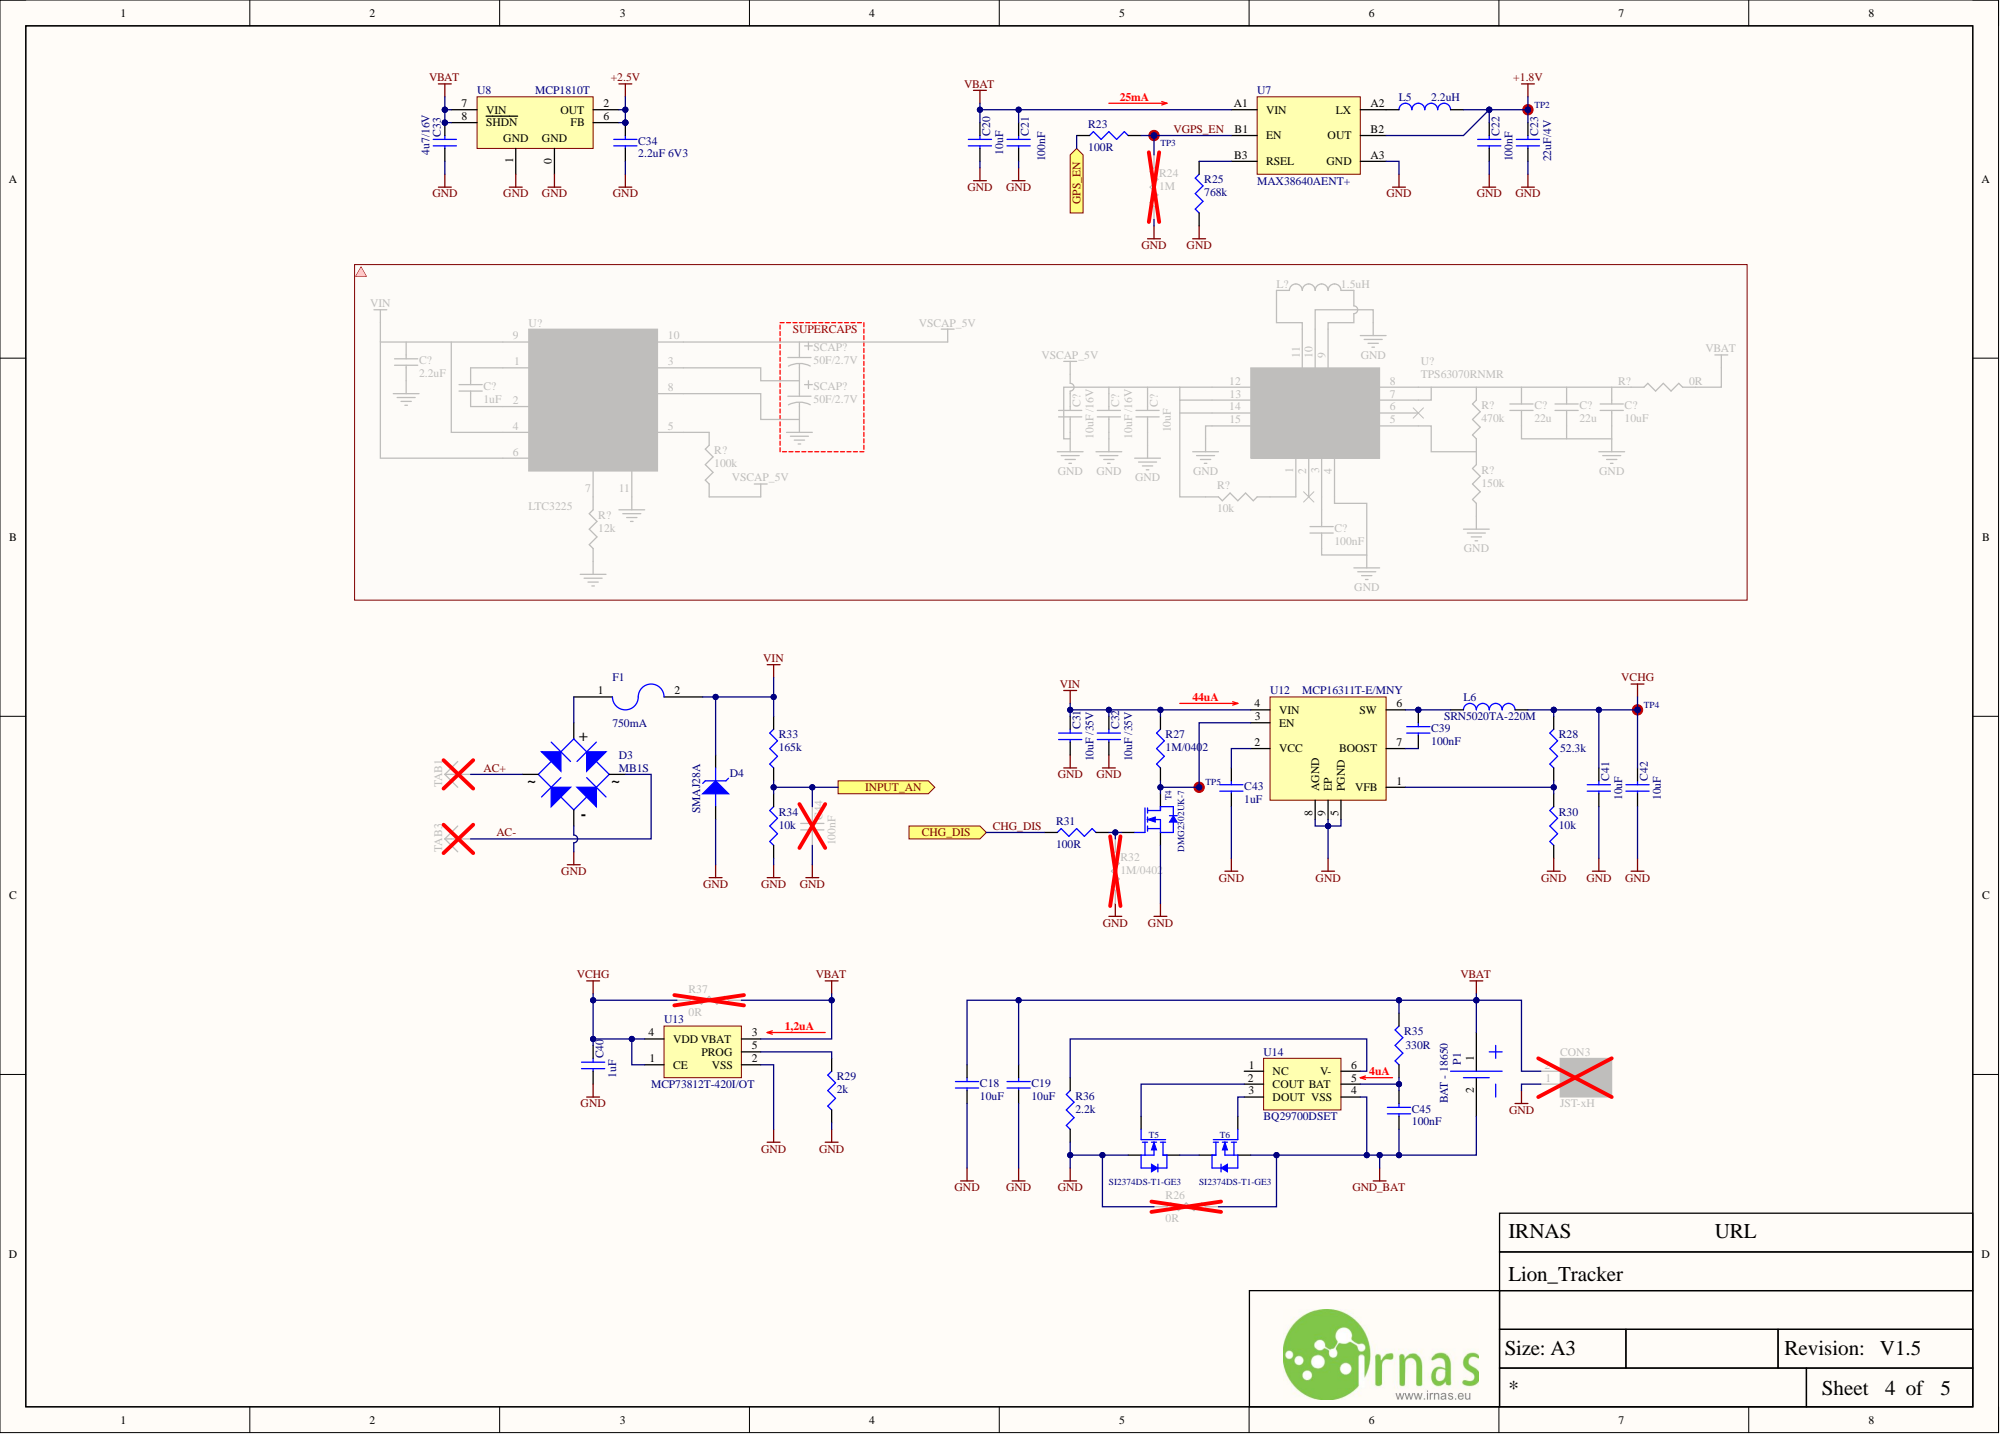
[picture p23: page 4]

VIN 13

VSEL 15

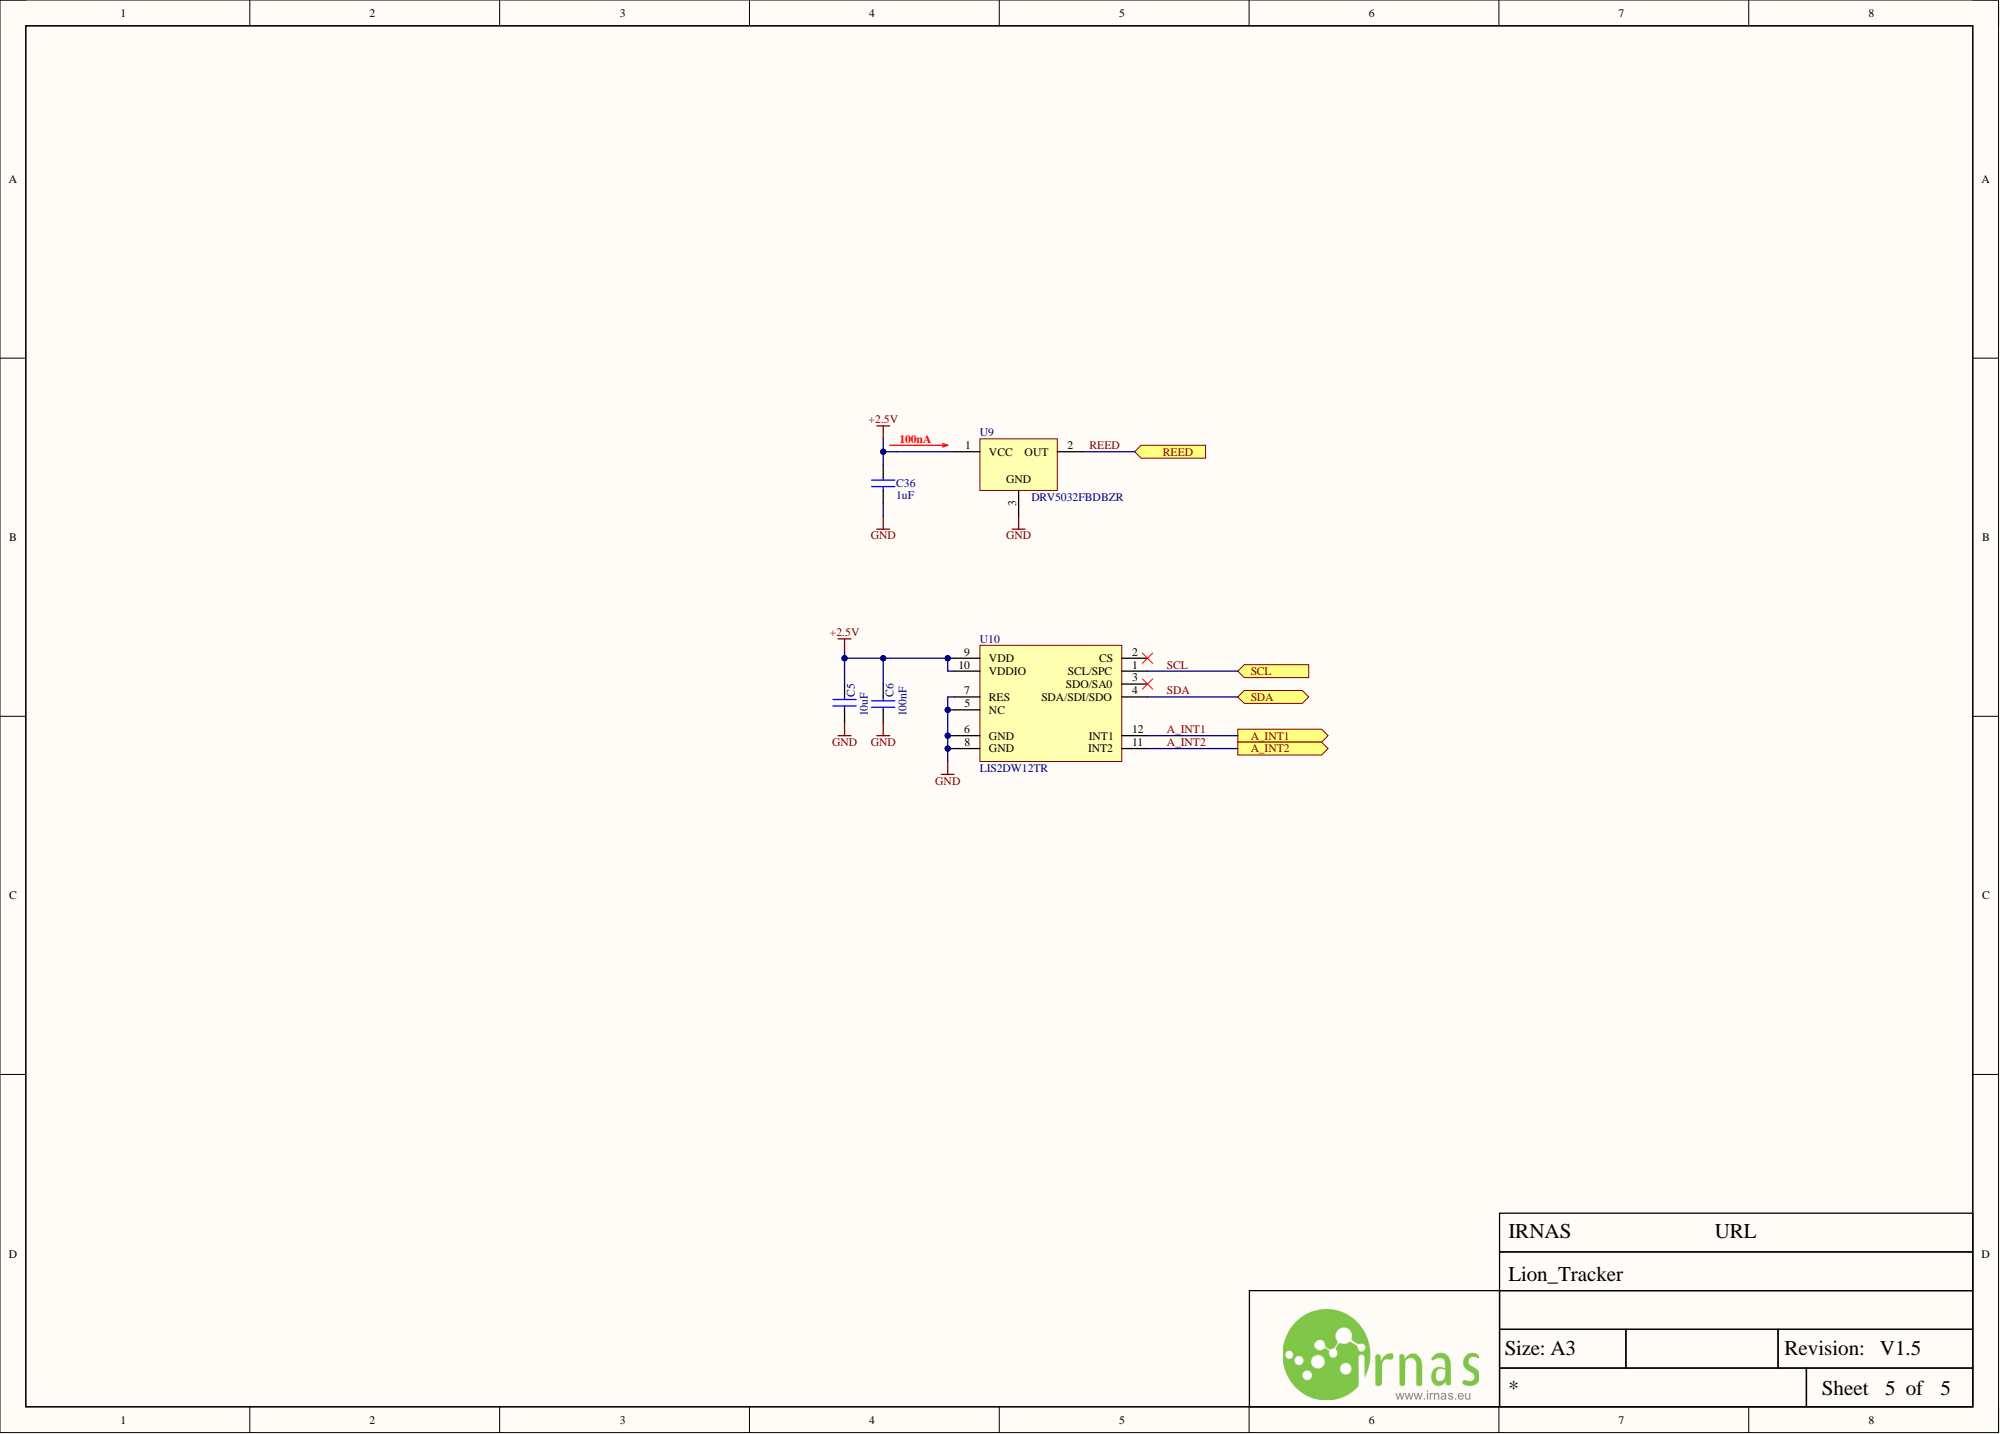
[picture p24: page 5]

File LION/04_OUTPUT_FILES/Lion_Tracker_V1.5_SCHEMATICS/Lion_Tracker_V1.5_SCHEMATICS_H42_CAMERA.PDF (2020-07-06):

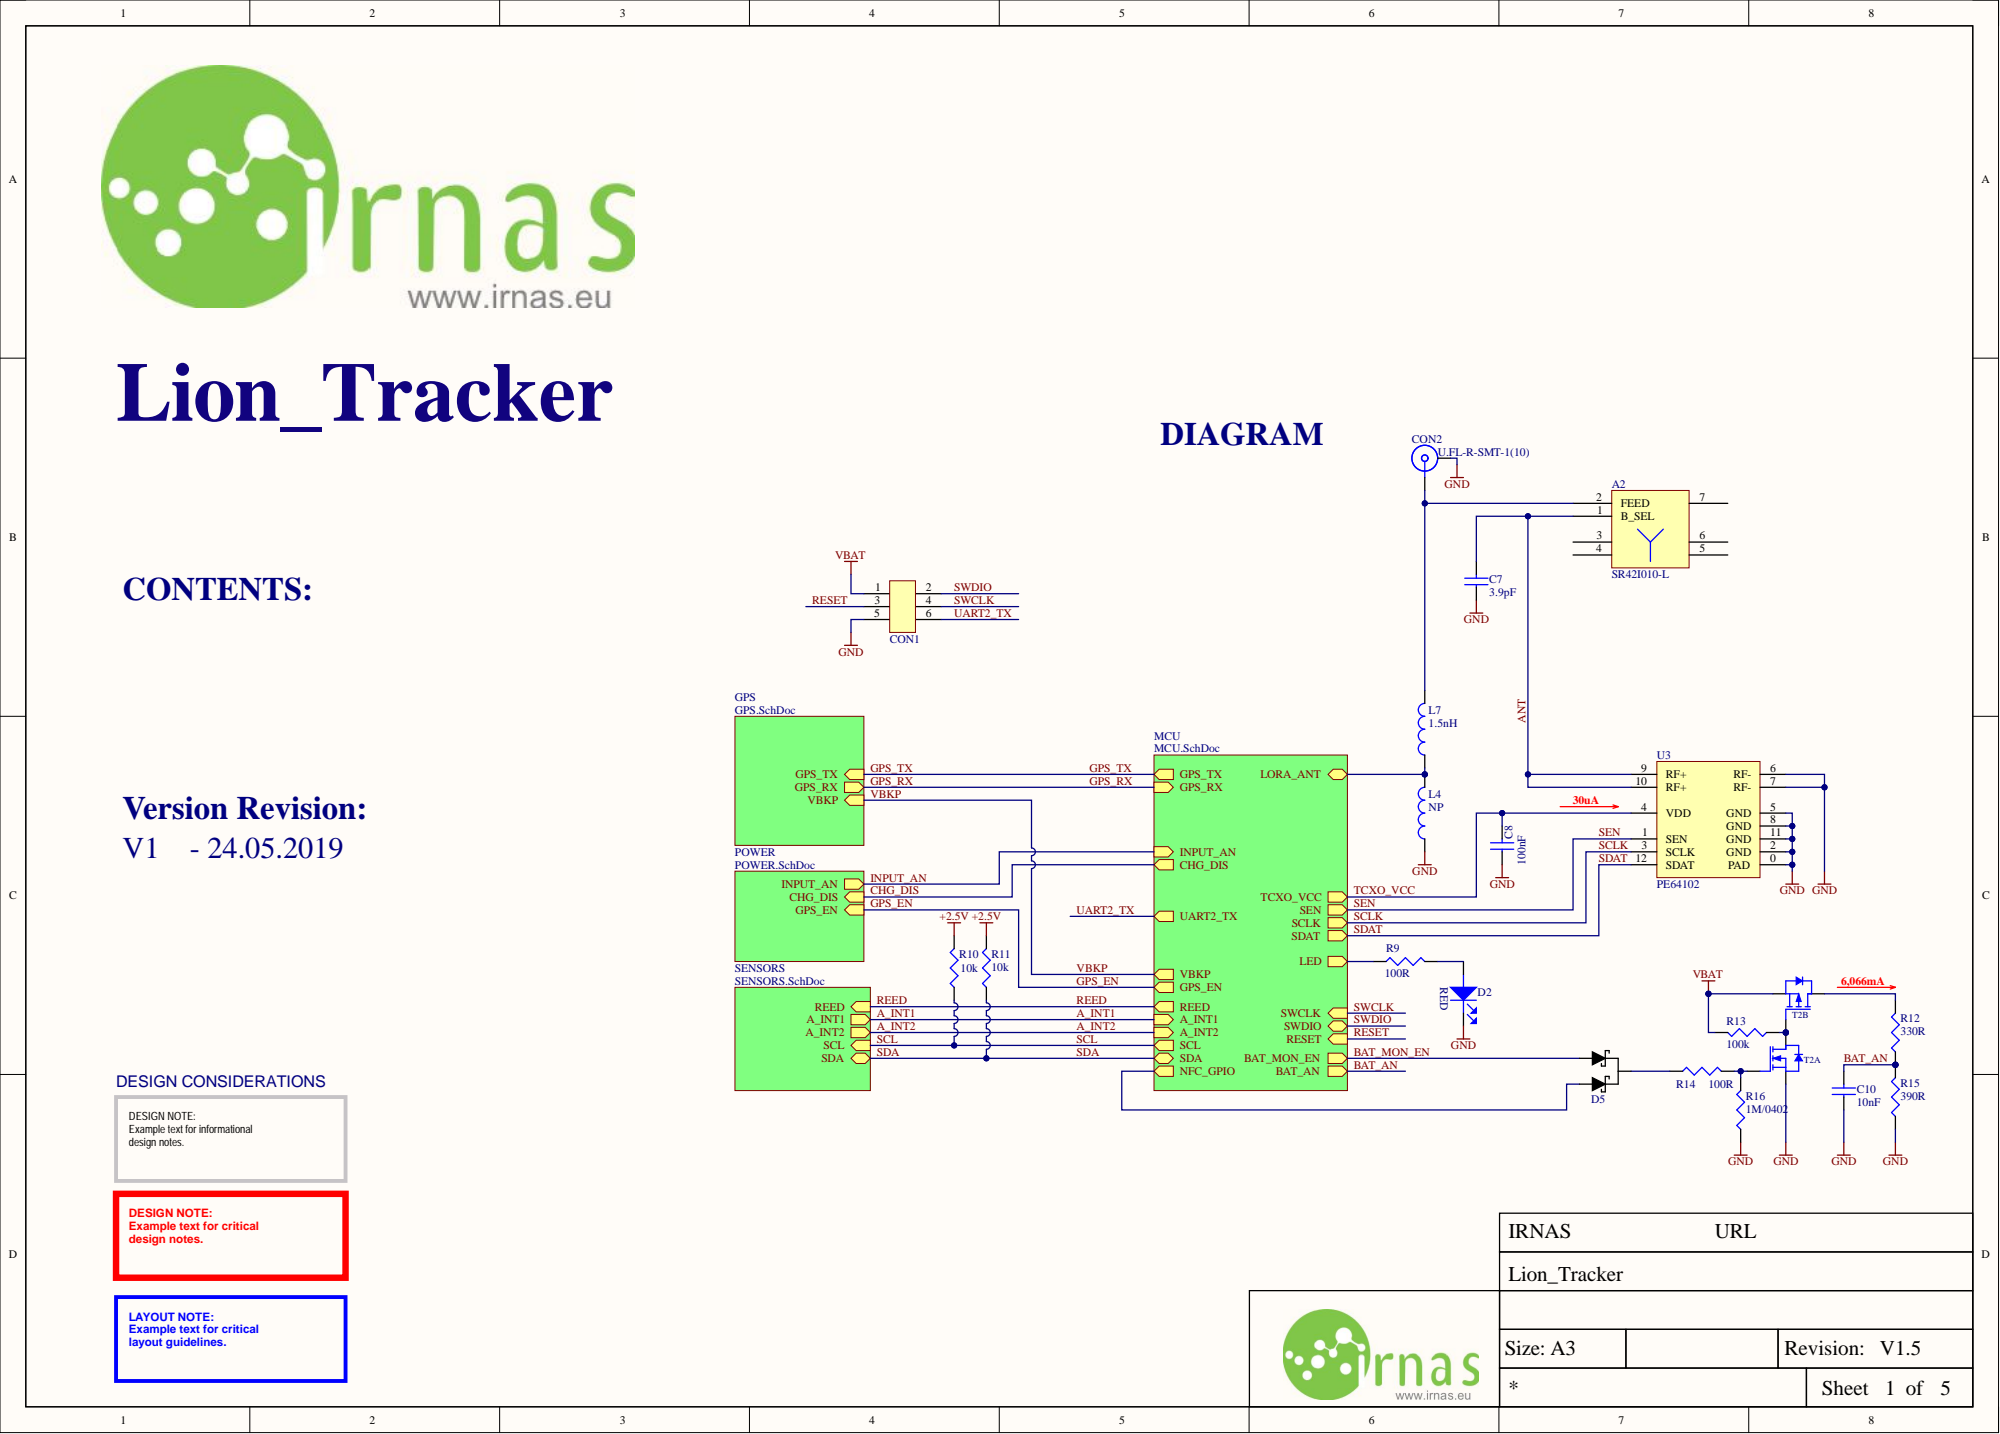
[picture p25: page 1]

SEN SCLK SDAT | 3 | | 2

SDAT 12 | 0

INPUT_A N | | | GND
CHG_DI S

UA RT2_TX | | TCXO_VCC SEN SCLK SDAT

DESIGN NOTE:
Example text for informational
design notes.

Example text for critical

LAYOUT NOTE:
layout guidelines.

Size: A3 | | Revision: V1.5

Sheet of


GND 50 GND 51 GND 52 GND 53


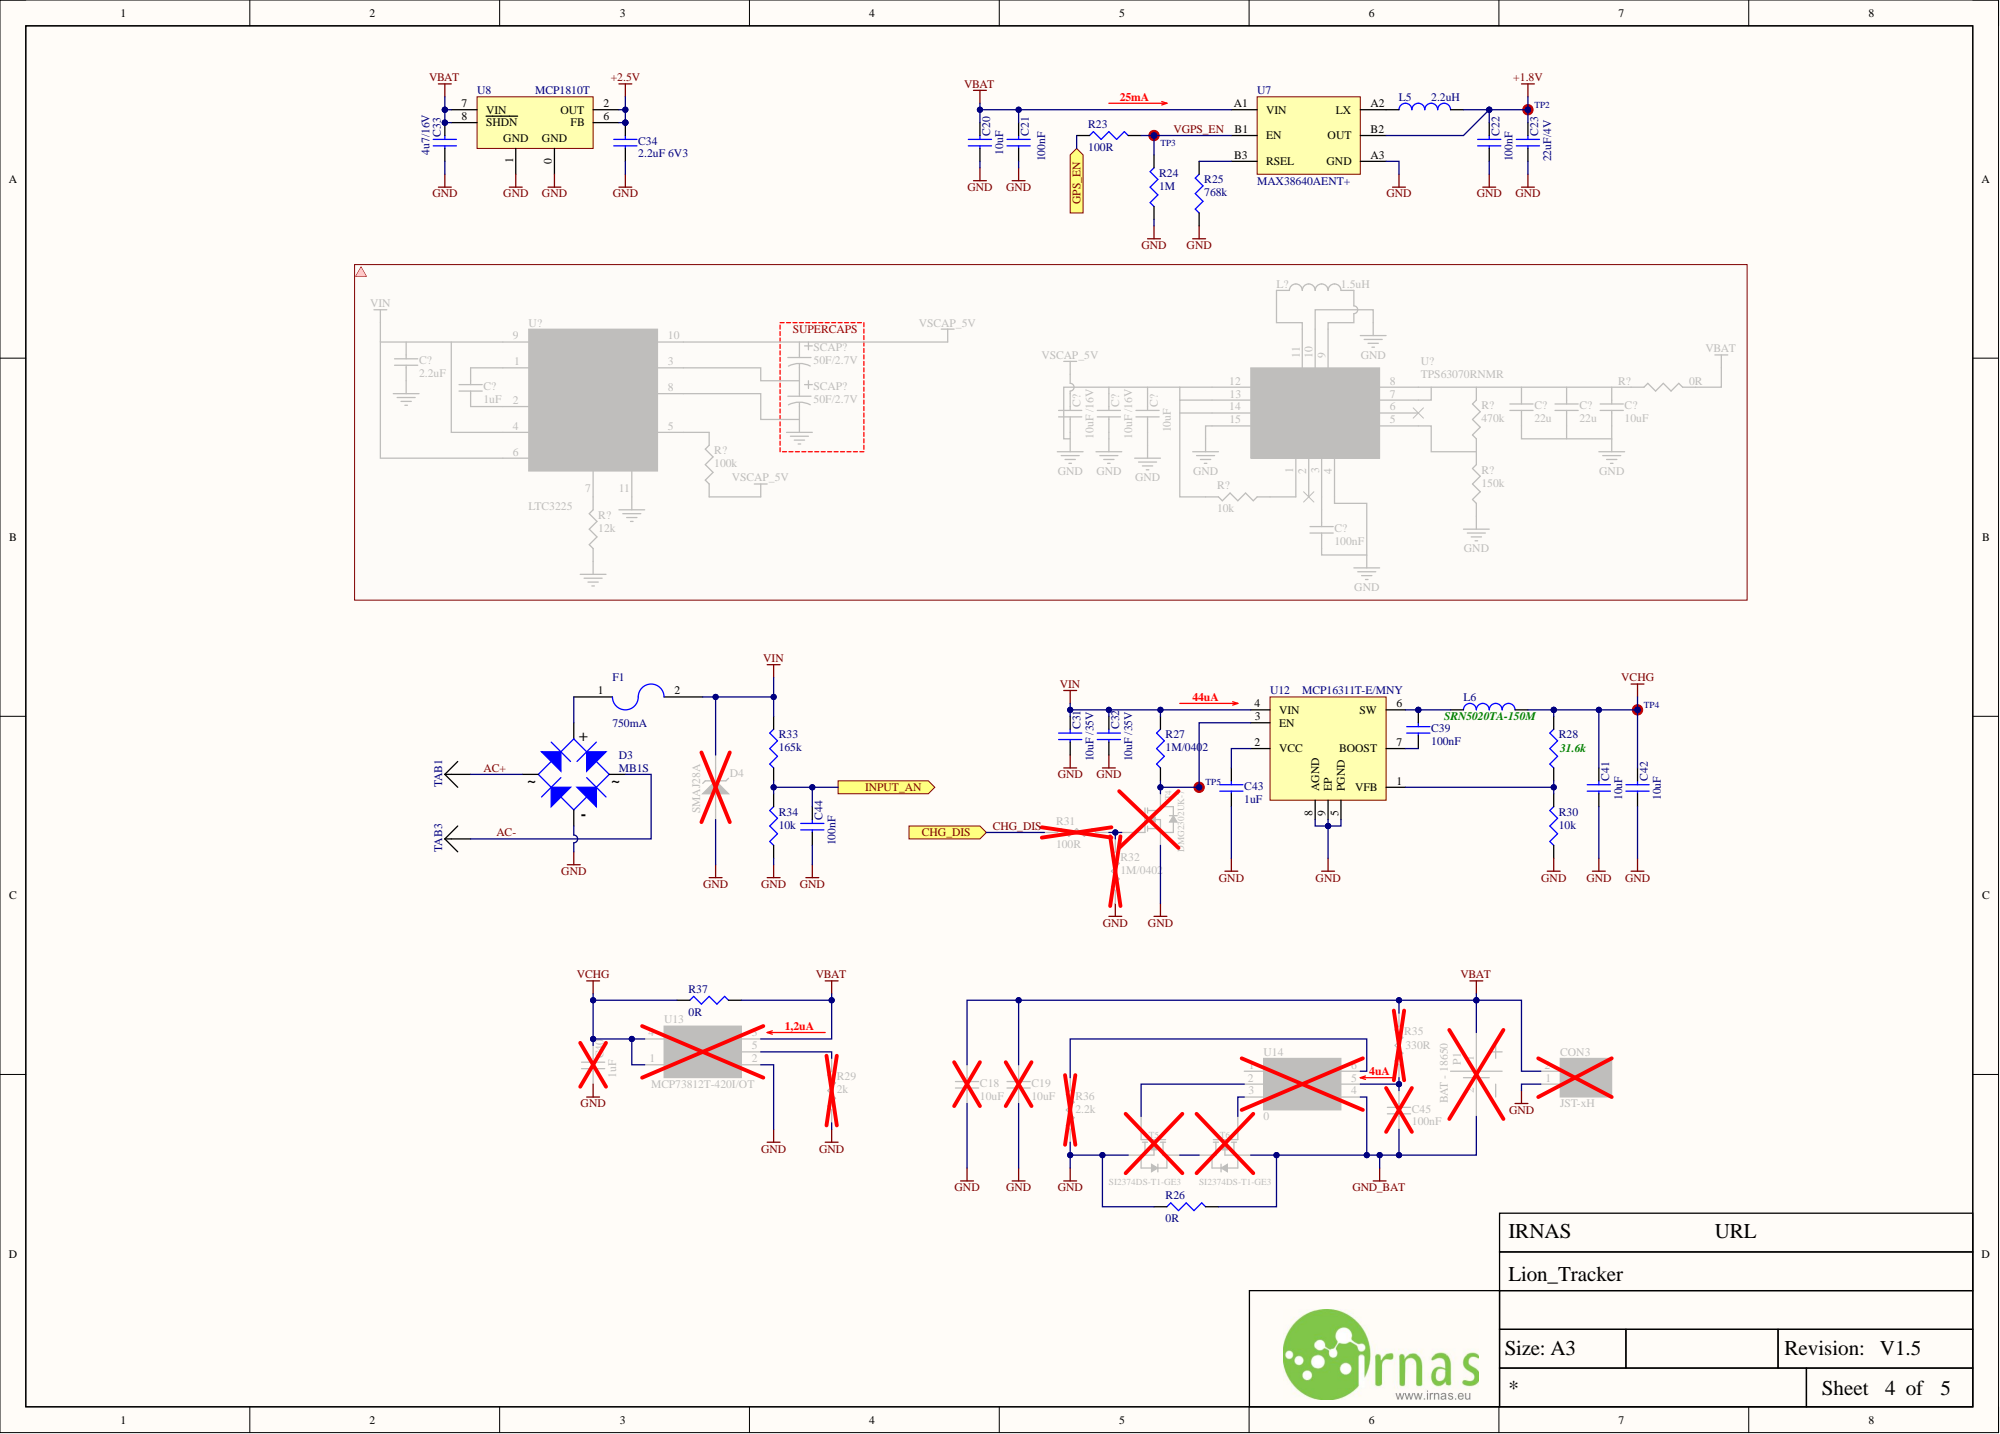
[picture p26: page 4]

VIN 13

VSEL 15


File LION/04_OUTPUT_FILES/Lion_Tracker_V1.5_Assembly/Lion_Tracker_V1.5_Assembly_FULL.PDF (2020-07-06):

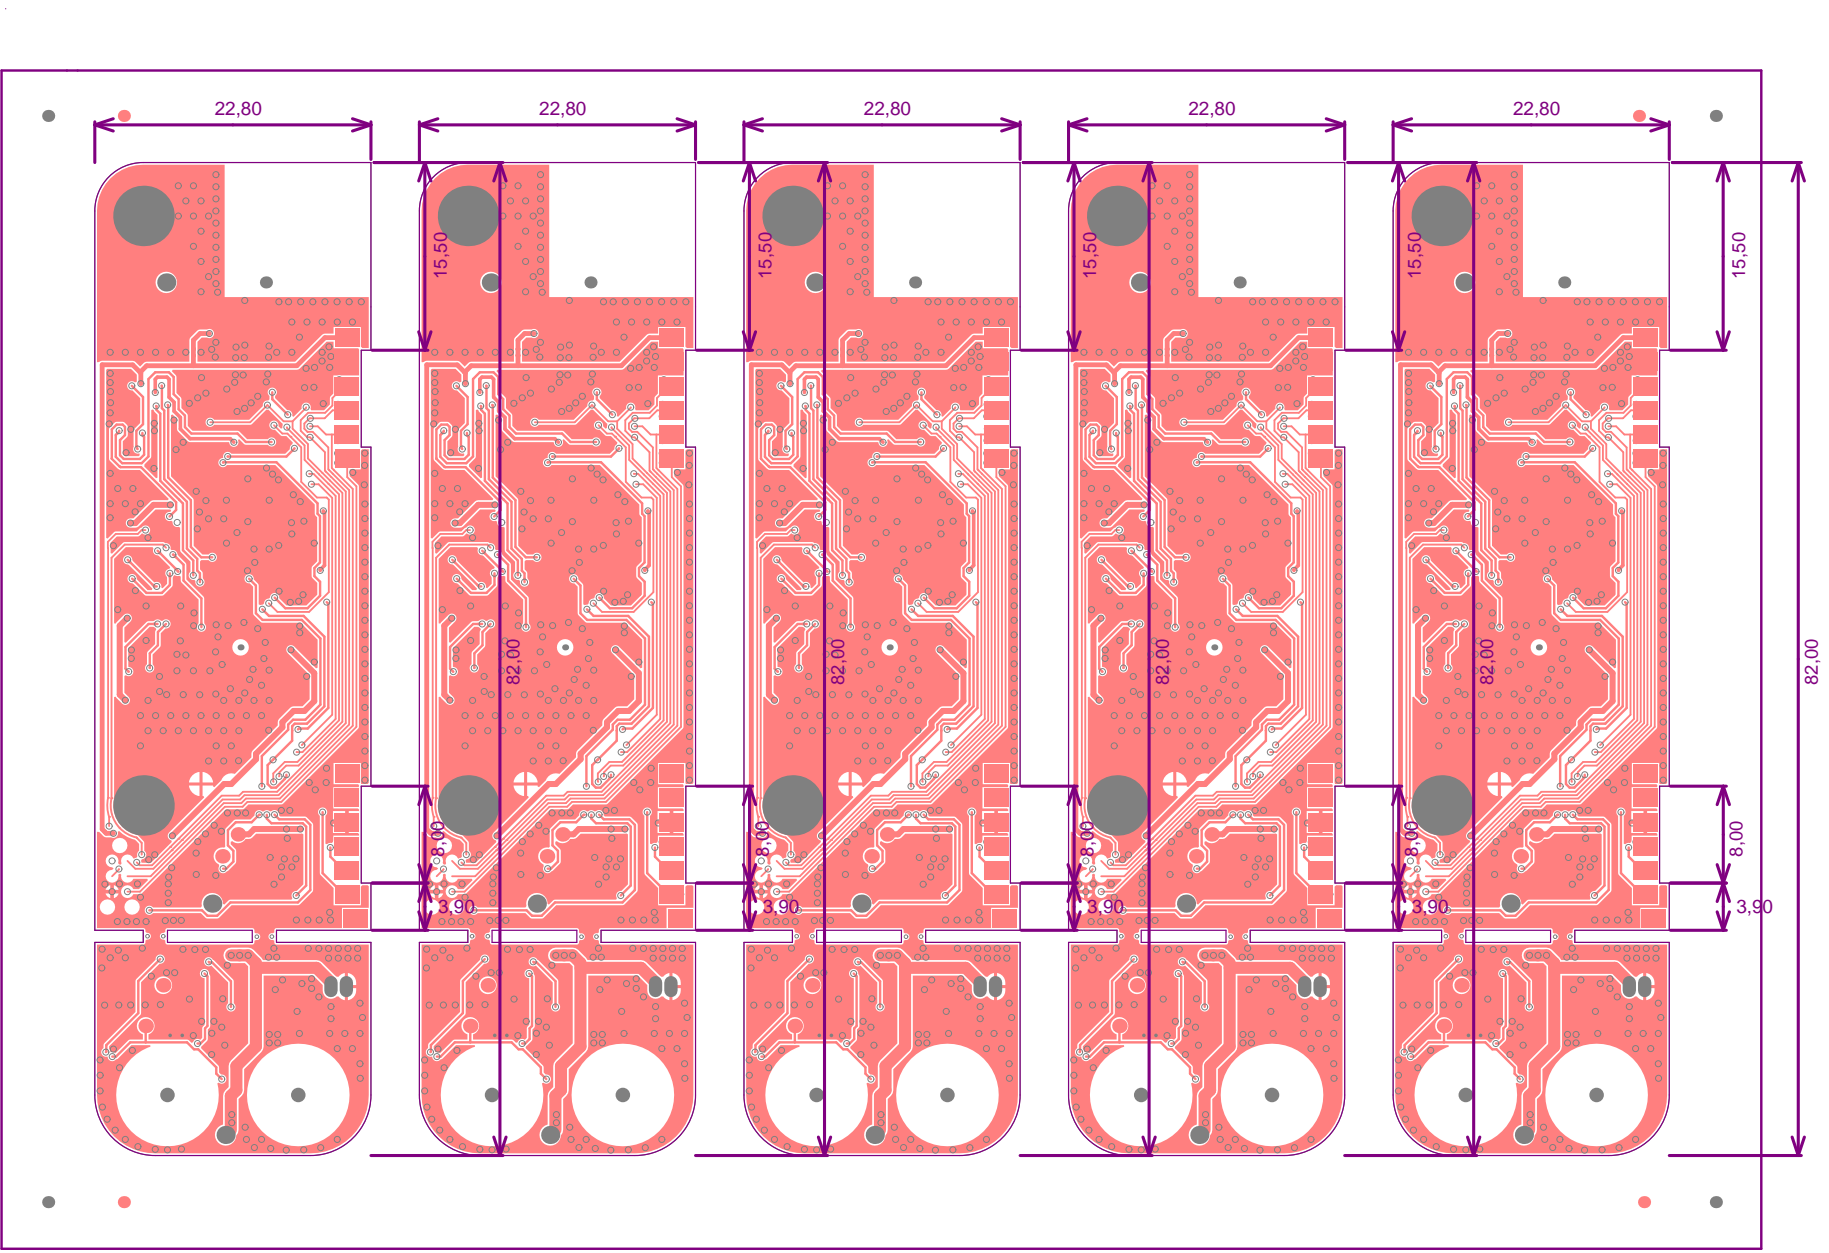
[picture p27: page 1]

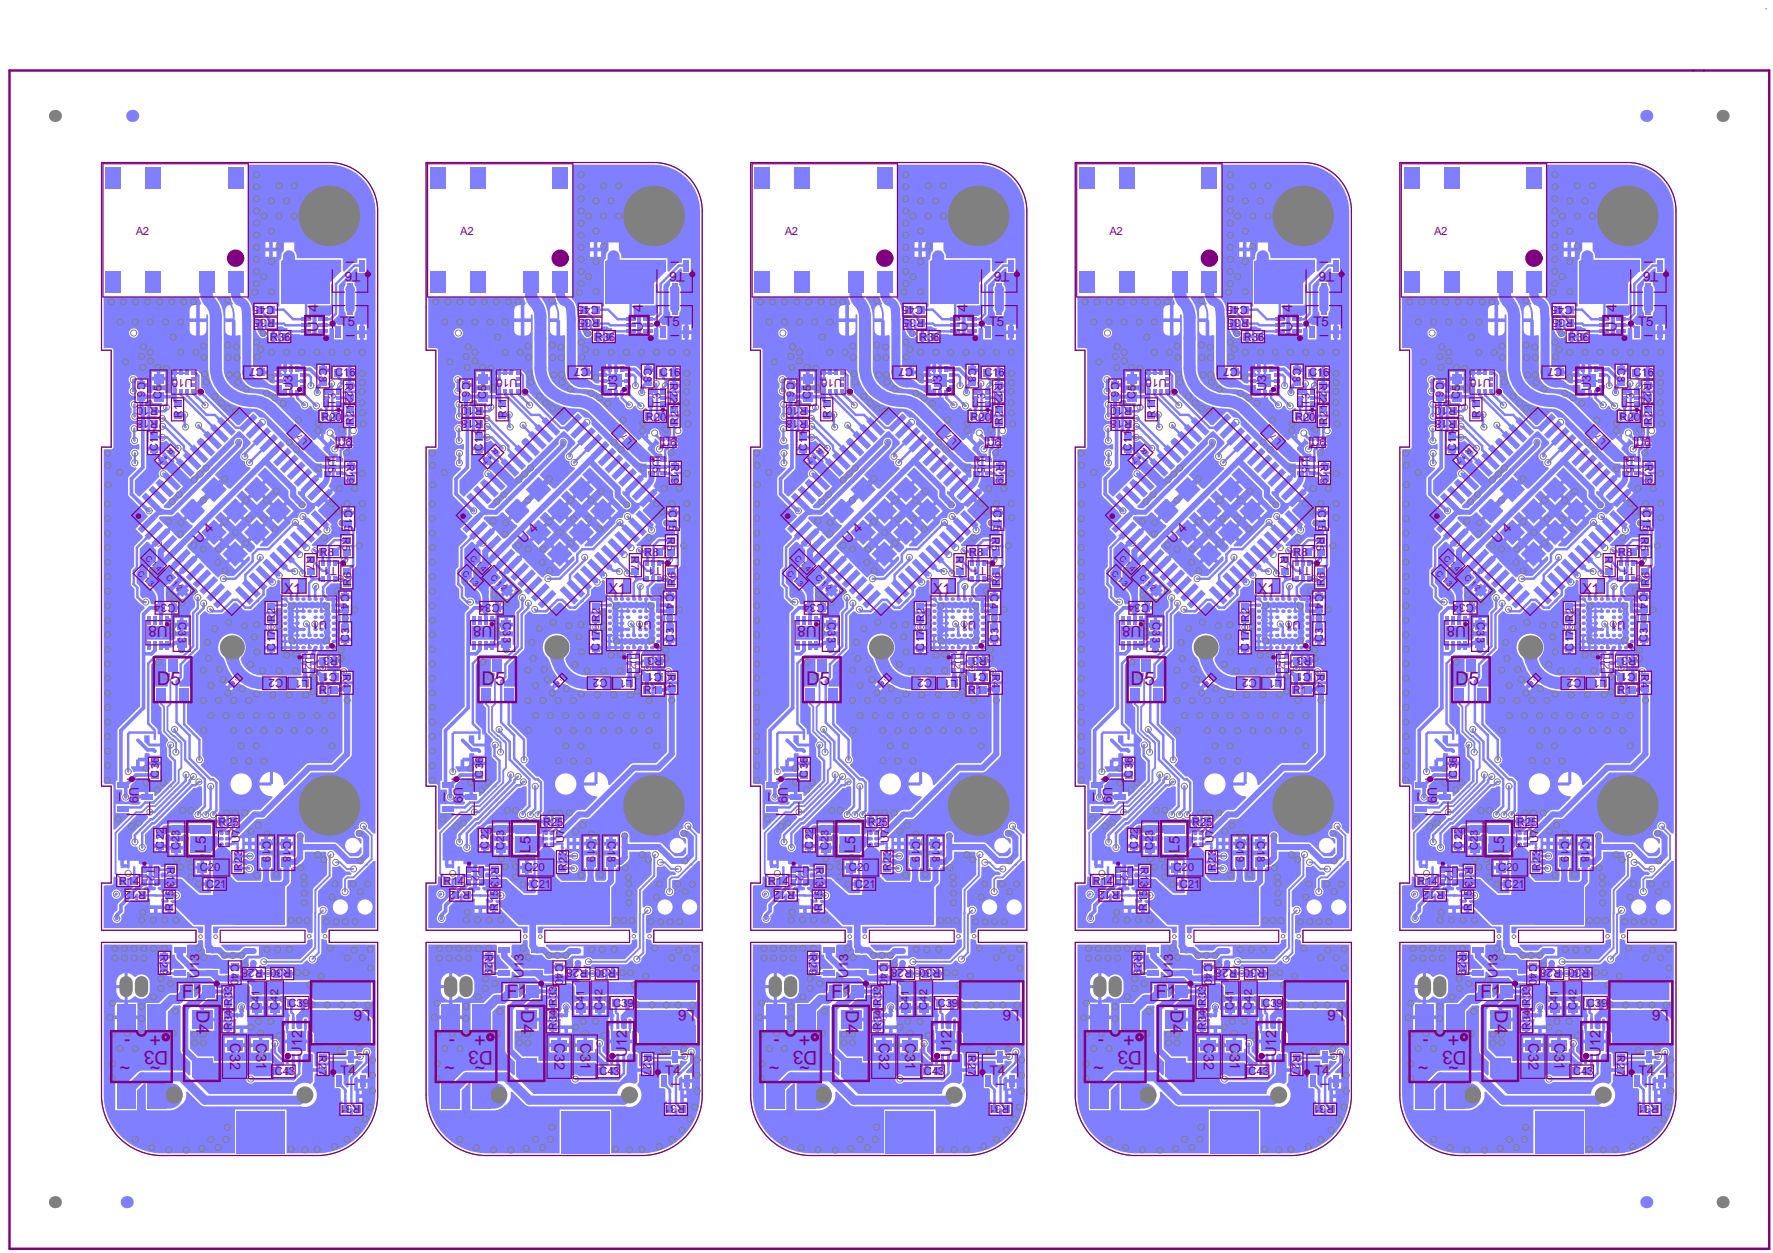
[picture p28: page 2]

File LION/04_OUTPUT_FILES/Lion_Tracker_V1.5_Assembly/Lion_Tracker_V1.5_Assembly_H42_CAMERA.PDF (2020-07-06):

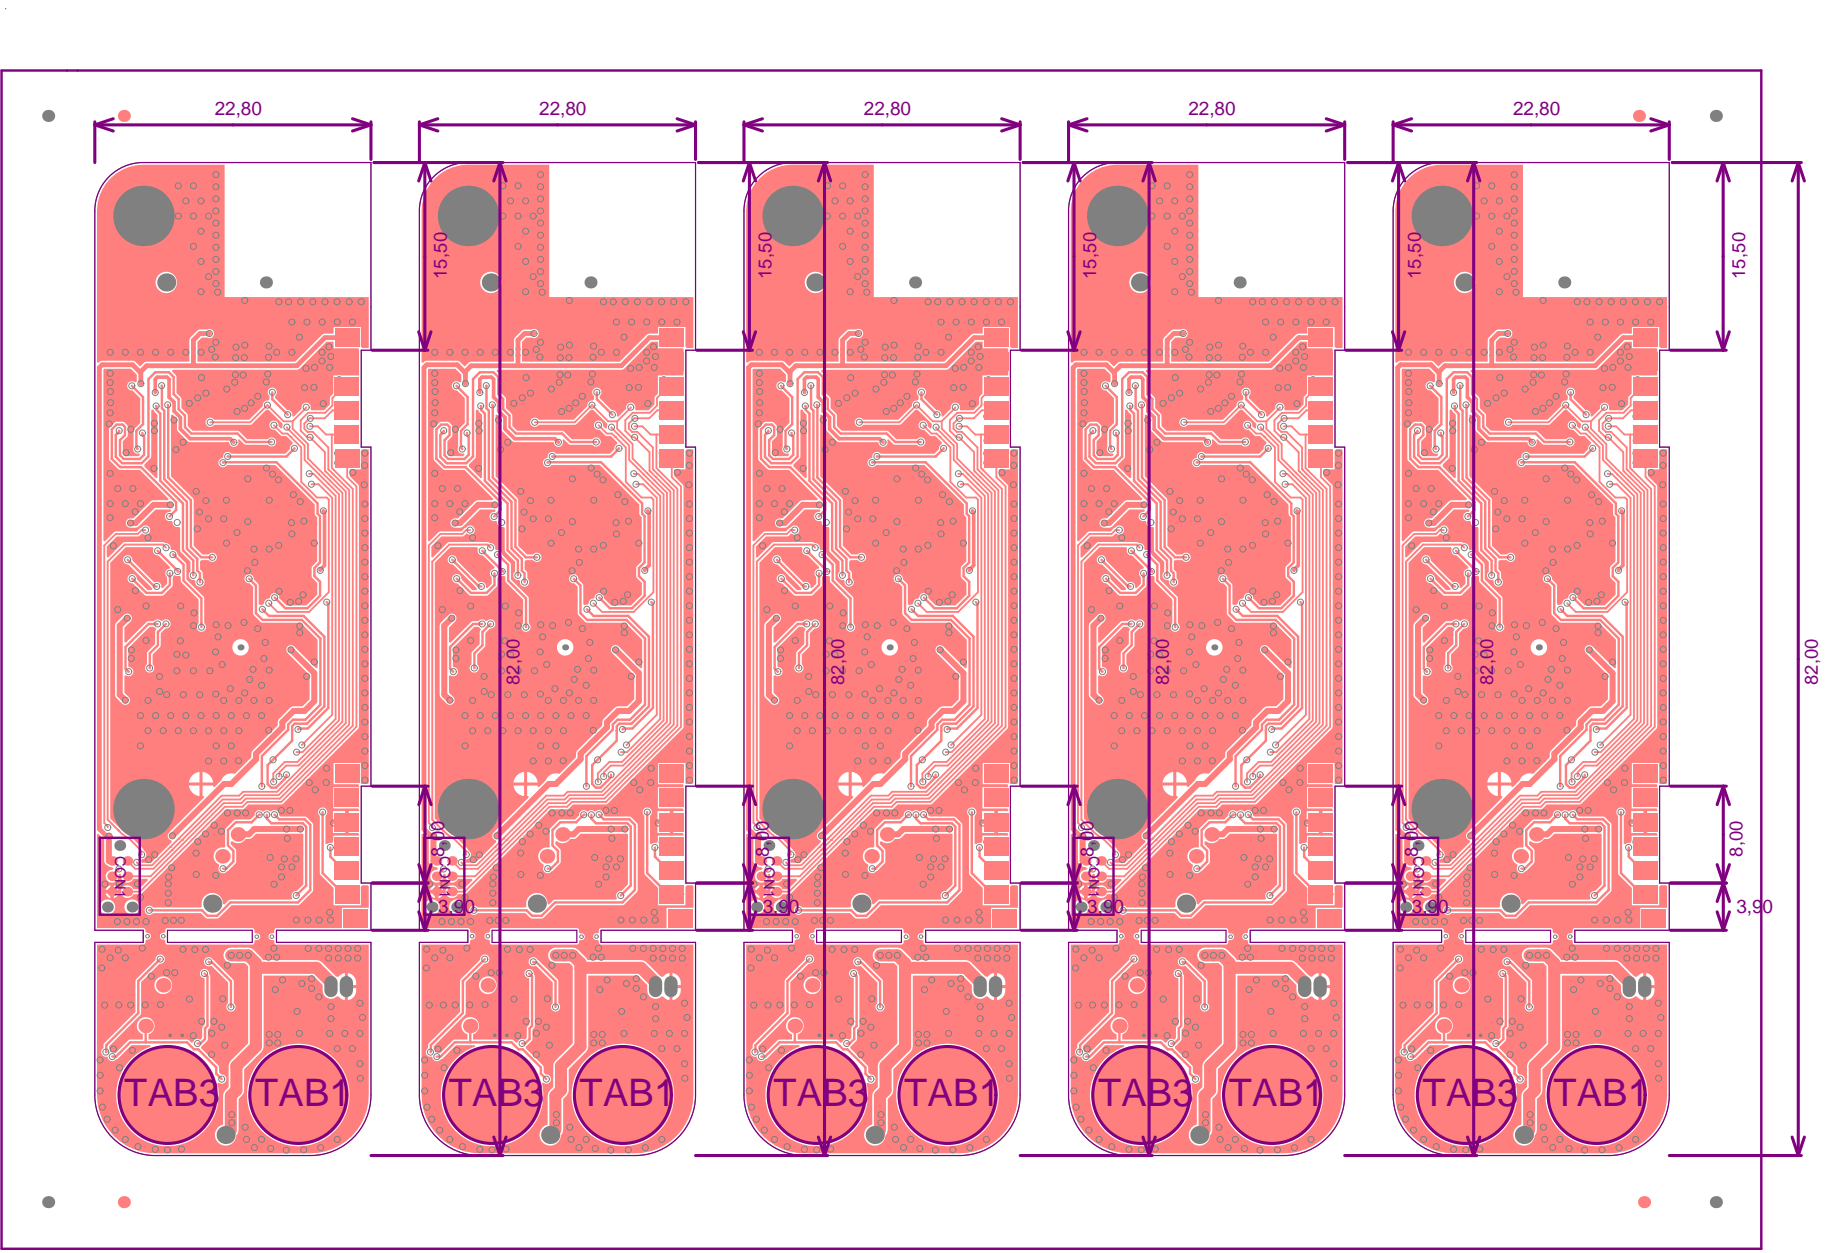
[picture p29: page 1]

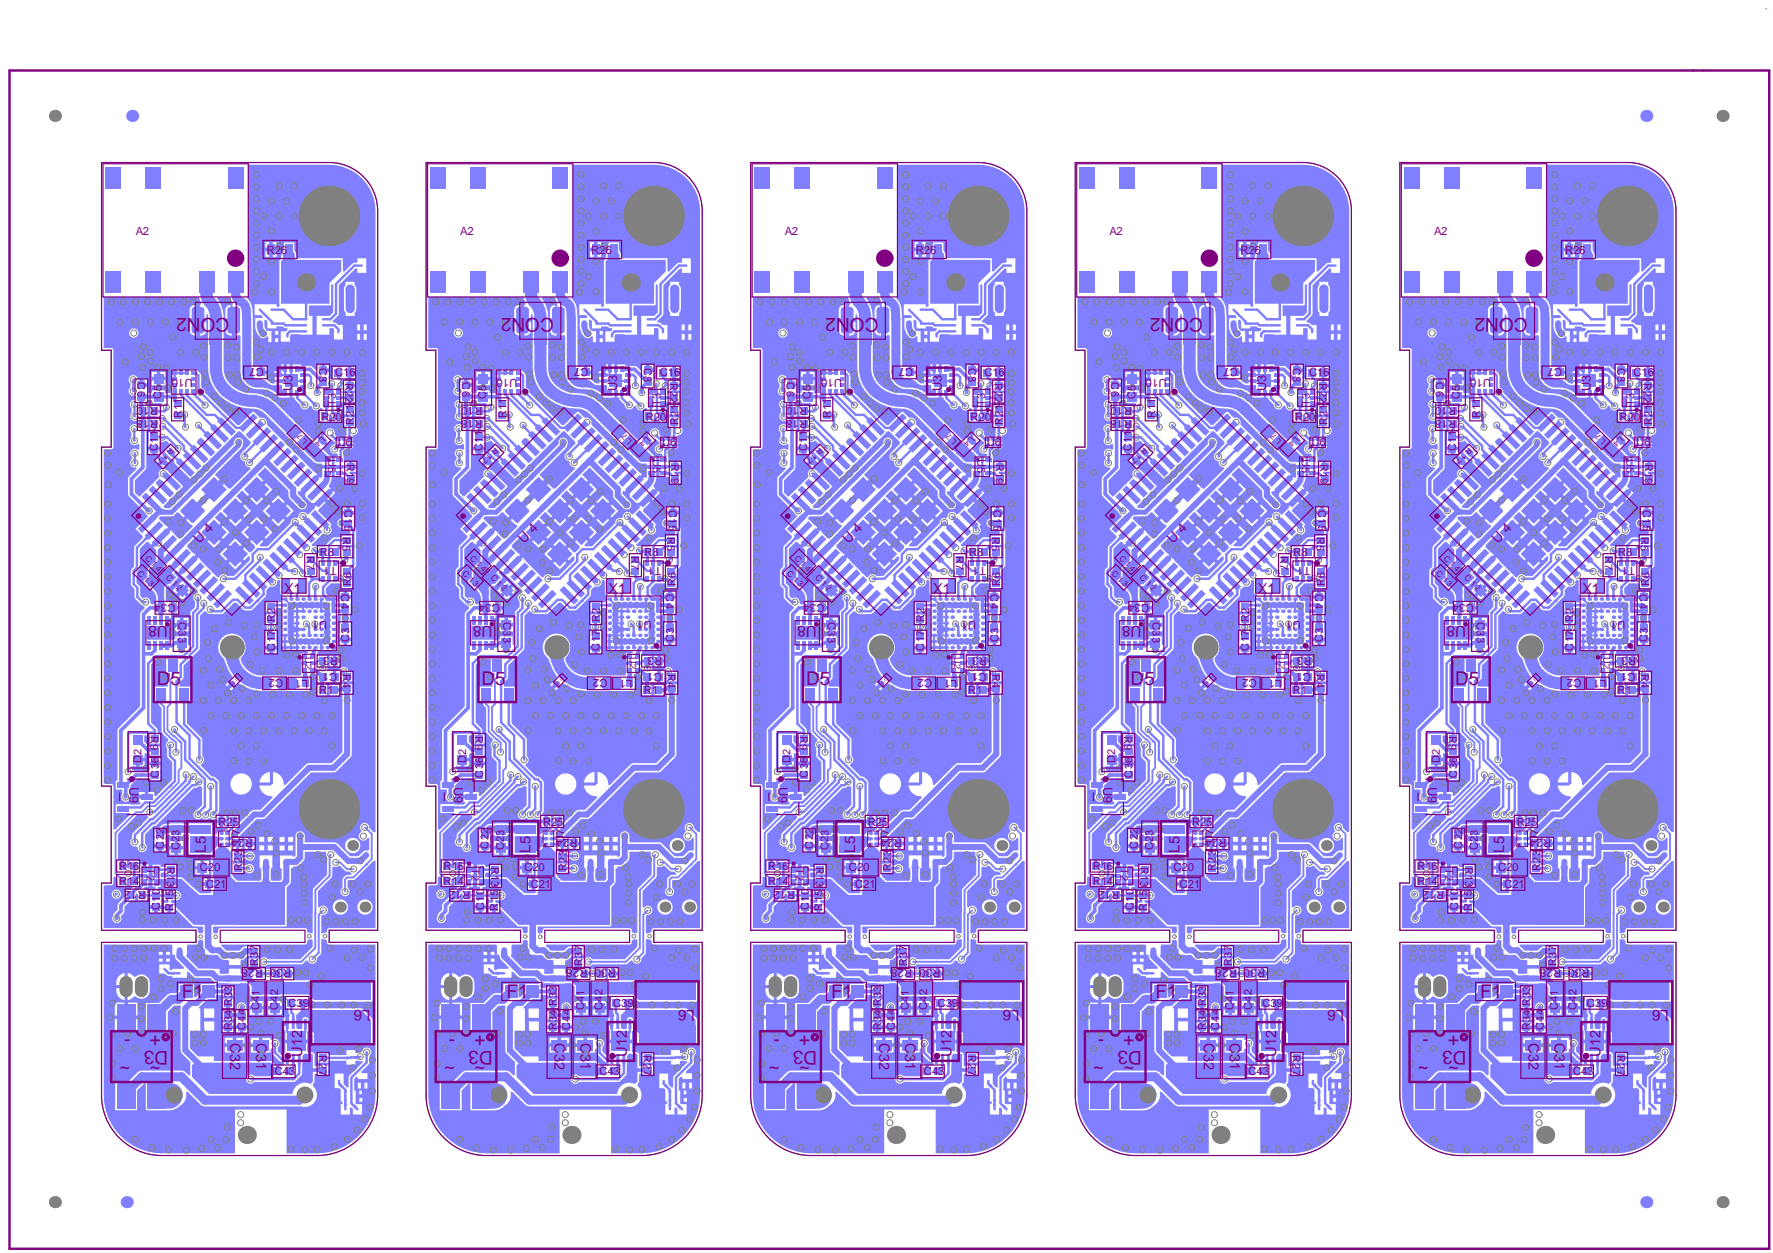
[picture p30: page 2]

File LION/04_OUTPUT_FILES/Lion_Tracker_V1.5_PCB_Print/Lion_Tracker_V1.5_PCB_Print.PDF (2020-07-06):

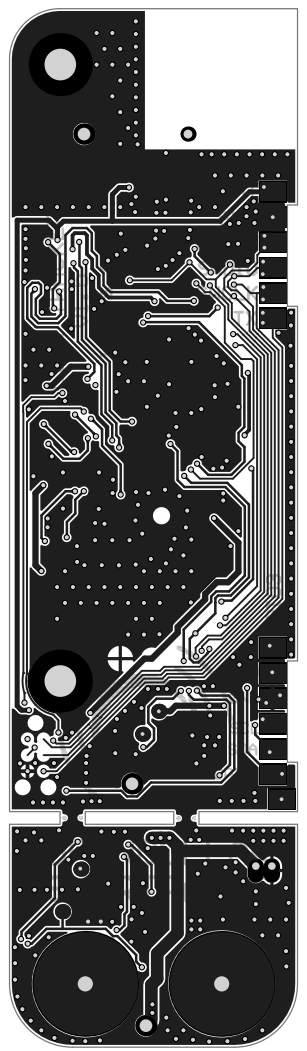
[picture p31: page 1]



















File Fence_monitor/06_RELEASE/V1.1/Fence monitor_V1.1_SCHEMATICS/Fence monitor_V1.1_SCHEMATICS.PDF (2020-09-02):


DESIGN NOTE:
Example text for informational
design notes.

Example text for critical

LAYOUT NOTE:
layout guidelines.

Size: A3 | | Revision: V1.1

* | Sheet 1 of 3



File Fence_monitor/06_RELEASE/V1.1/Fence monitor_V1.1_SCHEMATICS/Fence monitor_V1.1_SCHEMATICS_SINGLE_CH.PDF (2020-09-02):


DESIGN NOTE:
Example text for informational
design notes.

Example text for critical

LAYOUT NOTE:
layout guidelines.

Size: A3 | | Revision: V1.1

* | Sheet 1 of 3



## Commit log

2020-03-19 firs commit
    [ACCEL.SchDoc, GPS.SchDoc, LION_TRACKER_PANEL.PcbDoc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]
2020-07-06 Update to version V1.5
    [GPS.SchDoc, LION_TRACKER_PANEL.PcbDoc, Lion tracker.PrjPCB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]
2020-09-02 Added Fence monitor
    [ACCEL.SchDoc, ADC.SchDoc, ANALOG.SchDoc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]
2020-09-02 ReadMe fix
    [FENCE_MONITOR.PcbDoc, FENCE_MONITOR_PANEL.PcbDoc, FENCE_MONITOR_PANEL_BOT.PcbDoc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]
2020-09-02 Folder structure update
    [FENCE_MONITOR.PcbDoc, FENCE_MONITOR_PANEL.PcbDoc, FENCE_MONITOR_PANEL_BOT.PcbDoc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]
2020-09-28 Fance monitor V1.1 update
    [Fence monitor_V1.1.DRL, Fence monitor_V1.1.GBL, Fence monitor_V1.1.GBO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]
